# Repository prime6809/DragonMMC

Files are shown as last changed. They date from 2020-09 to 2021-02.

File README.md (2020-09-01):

# DragonMMC
This is the source repository for the DragonMMC project.

Currently it contains the following components :

6809 firmwars as exceuted by the CPU in the Dragon or CoCo.
AVR firmware as executed by the AVR microcontroller.
CPLD firmware as programmed into the XC95144XL CPLD chip on the board.

Various use and API documents are included in the Doc directory.

The primary developer uses the following environment to build the 
firmware : Programmer's notepad under windows, along with Cygwin.
The different firmwares are built using a Makefile.
Please see BUILD.txt in the Docs+explorer directory.

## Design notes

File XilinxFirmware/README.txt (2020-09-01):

Building Xilinx firmware

Open up project in Xilinx Webpack.

Select DragonMMC.v in the hierachy view.
Expand "Implement design" in the process view, and then double click on 
"generate programming file".
Once the programming file is complete double click on "configure target device".
Click OK to open impact (in a new window).

Within Impact :
Double click on "boundry scan" within "impact flows", this will open up a big 
blank pane with "Right click to add a device to the JTAG chain" in it.
Right click within this pane and from the popup menu select :
	Output file type->XSVF file->Create XSVF file.
	Enter an outout file name e.g. DragonMMC.xsvf
	You will then be prompted for the JED file, select the DragonMMC.jed
	
The JTAG pane will nwo display a graphic representing the xc95144xl, right click 
on this and select program and then 'OK' in the popup, the 'device' then be 
programmed with output going to the XSVF file.

Once this is done copy the DragonMMC.xsvf to your SD card as DGNMMC.SVF 
**NOTE** case and filename! Then program as usual.

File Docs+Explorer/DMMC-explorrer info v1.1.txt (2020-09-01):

DMMC explorer
=============

VARS
====
TRUE
FALSE
AEXEC true if AUTOEXEC is enabled
DS  true if DOS is enabled
CLOCK if clock is enabled at boot
DOT	 true if ._ files are hidden 
MAX  number of items in the folder
MR   max number of rows on screen
CF   current file DI position
CP   Current cursor print @ position
REFRESH Bolean set if the screen and DI needs refrshing
UPDATE boolean true if the screen should be updated
FILES number of files on screen
NEX number of known file extensions
NBYTES number of bytes in the inverse function

CC Boolean true if the system is CoCo

ROW the current row (starts at 1)4020
COL the current col (0 or 1)
page the current page (starts at 0)

DI$ (1..255) list of the items in the folder, blank is last entry
MD$ (1..4) mounted disks
FEXT$ (1-10) known file extentions
CC$ Cursor string
BC$ blank cursor
KEY$ Key input
WD$ The current worklng directory

Temp VARS
=========
CH
II
WI
C
I
FERROR%		filter error string
invalid$
N$
IN$
KEY 		assci vall of KEY$
EXT$		selected file extention (after pressing enter)
YL
OKtrustno1

COL
A$

Clock VARS
==========
YY YY$
MM MM$
DD DD$
HH HH$
MI MI$
DT$

-------------------------------------------

FILE EXTENTION DATA
1 .CAS 2800
2 .ROM 2400
3 .VDK 6200
4 .DGN 2600
5 .BIN 2600
6 .BAS 2600
7 .SSD 3400
8 .CCO 2600
9 .DSK 6200
10.SSC 3400
11.CCC 2400

------------------------------------------

10-200   Setup

200-350  Draw explorer screen
350 INKEY$ main

950 Exit point
1000 Populate folder array list
1200 read config vars: AEXEC, DOS, CLOCK
1400 SET config from vars: AEXEC, DOS, CLOCK

2000 RETURN key
2400 load ROM
2600 load DGN/BIN/BAS
2800 load .CAS file
2900 change folder

3000 UP KEY
3200 populate mounted disks array  MD$ 
3400 Load Snapshot

4000 DOWN key
4500 Page down
4600 Page up
4700 @ key go down tree

5000 RIGHT key
5200 New Folder
5500 Set snapshot directory

6000 list mounted disks
6200 mount a disks
6500 unmount disks
6700 mount .CAS file

7000 delete a file
7500 Set dir filter

8000 Version Info
8200 Change boot option
8500 clock adjust

9000 work out the current DI$() position - updates into CF

9200 Draw horz line
9400 Menu for unkown file types
9700 set clock

10000 HELP

20000 DATA for file extensions
20100 populate FEXT$ array
20200 Inverse DATA code
20400 Poke in the inverse function

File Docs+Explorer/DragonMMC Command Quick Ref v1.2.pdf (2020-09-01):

Date 22/09/2019 | V1.2

DragonMMC Quick Refernce Guide

Commands

CAT “pattern”
Lists the files in the current directory of the memory card that match the pattern. If no pattern is given, then all files are displayed.

CATP “pattern”
Lists the files in the current directory of the memory card that match the pattern. When no pattern is given, then all files are displayed. If the number of files exceeds what can be displayed on screen the results will be paged.

CWD “dirname”
Changes the current directory on the memory card to the specified directory.

CWDS “dirname”
Sets the directory where snapshots are saved. Dragon and CoCos have separate folders and must be set separately on each computer.

HELP / HELPX
Displays DMMC version information.

MCARTLOAD “filename”
MCARTLOADA “filename”
Loads the specified ROM file into the MMC card ram in the $C000-$FFEF area. Note: doing so will overwrite the MMC rom so MMC functions will no longer be available. MCARTLOADA allows the use of auto-starting cartridge images.

MCAS
Places the machine into cassette emulation mode, allows the use of emulator .CAS files with CLOAD, CSAVE etc.

MDELETE “filename”
Deletes the specified file from the current directory of the memory card, you will be prompted before deletion.

MDISK ON
Turns on disk emulation for the current platform and perform a cold reset.

MDISK OFF
Turns off disk emulation for the current platform and perform a cold reset.

MDISKC driveno,”filename”
Creates a blank disk image with the filename in drive driveno (1-4 for Dragon, 0-3 for CoCo). The disk image will require formatting before use (i.e. DSKINIT or DSKINI).

MDISKI driveno,”filename”
Mount disk image filename in drive driveno (1-4 for Dragon, 0-3 for CoCo).

MDISKL
List mounted disk images.

MDISKO driveno
Dismount disk image from driveno (1-4 for Dragon, 0-3 for CoCo).

MFILEC “file1”, “file2”
Copy file1 to file2.

MFILER“file1”, “file2”
Rename (or move) file1 to file2.

MMIRROR “filename”
MMIRRORA “filename”
Mirrors tape data as it’s loaded into the computer to a CAS format file. Type CLOAD or CLOADM to load a program, once loaded, press the snapshot button to finish the process.

MKDIR “dirname”
Creates the specified directory, on the memory card.

MLOAD “filename”
MLOAD “filename”, location
MLOADA “filename”
MLOADC “filename”
Load the previously saved BASIC or machine code program from the memory card. MLOADA will automatically RUN/Execute the program once loaded. MLOADC operates as MLOADA but first clears any active program and returns the machine to its power on state

MLOADS “filename”
Loads a previously saved snapshot from the memory card.

MMOUNTC
Closes the currently open cassette image file.

MMOUNTR “casfile”
Mounts a CAS file in read only mode.

MMOUNTW “casfile”
Creates and mounts a CAS file in write mode.

MSAVE “filename”
MSAVEM “filename”, start, end, entry
Save the BASIC or machine code program to the memory card. Note: the filename is used as specified and no extension is added.

MSETCFG flags
MSETCFG flags , <platform>
Set the configuration flags for the interface, value should be a bitwise or of the following values. Valid platform is:-
0 | System
1 | Dragon
2 | CoCo
If no platform is specified then the current platform (Dragon or CoCo) is assumed.

Valid flags for the System (DMMC) platform:-
Hex | Dec | Purpose
&H80 128 | Enable firmware updating from the memory card the next time
| | it is rebooted. **
&H04 4 | Enable auto .BAK creation when using MSAVE
&H02 2 | Disable the display of files beginning with ‘ ._’
| | (dot)(underscore) or ‘ _ ‘(underscore). This allows hiding of
| | Apple Mac meta data files.
&H01 1 | Enable debugging information to be sent to the AVR’s TTL
| | serial port.
** The firmware update flag is reset after a successful firmware update.

Valid flags for the Dragon and CoCo platforms:-
Hex | Dec Purpose
&H40 64 | Enable execution of the “AUTOEXEC” file, this should be a
| | BASIC program saved with MSAVE
&H20 32 | Enable DragonDOS (Dragon) or RSDOS (CoCo) emulation using
| | disk images. Also set by MDISK ON / MDISK OFF
&H10 16 | Enable the display of real time clock data and time at boot up.
&H08 8 | Enable the display of the firmware compile date at start-up.

MSETCFGCflags
MSETCFGC flags , <platform>
MSETCFGC will clear any bit that is set in the config byte, and leave alone any that is clear.

MSETCFGS flags
MSETCFGS flags , <platform>
MSETCFGS will set any bit that is set in the config byte, and leave alone any that is clear.

MSETDT “YYYY-MM-DD hh:mm:ss”
Set the real time clock date, used for date stamping files. Format MUST be:-
YYYY | Year 2000-2099
MM | Month 01-12
DD | Day of month 01-31
hh | Hour in 24 hour format 00-23
mm | Minutes 00-59
ss | Seconds 00-59
Note, that you must use a leading zero for values less than 10!

MTAPERUN “filename”
Turns on tape emulation, mounts the specified file as read only and loads the first file from the emulated tape. The first file loaded is automatically executed.

RETOKC
Re-tokenize the BASIC program in memory from Dragon to CoCo.

RETOKD
Re-tokenize the BASIC program in memory from CoCo to Dragon.

REWIND
Rewinds the cassette image file (.CAS) loaded into the virtual DMMC tape recorder.

Functions
Note: Functions ending in $ return a string, all others return an integer.

CFTYPE
Get the file type of the next file on an emulated cassette.
0 = BASIC, 1 = ASCII data/BASIC, 2 = Binary data or Machine Code, 255 = Invalid

CFTYPEE
Get the EXEC address of the next file on an emulated cassette.

CFTYPEL
Get the load address of the next file on an emulated cassette.

FINDFIRST$ “pattern”
Finds the file first based on the pattern, subsequent calls should be made to FINDNEXT$ Returns an empty string if no files are found.

FINDNEXT$
Finds the next file in the sequence started by FINDFIRST$ Returns an empty string when no more files are found.

MGETCFG
MGETCFG(<platform>)
Get the configuration flags, see MSETCFG for details, if no platform is supplied then the current platform (Dragon or CoCo) is assumed. See MSETCFG for details of the flags and platform. MGETCFG(255) can be used to find the current computer, 1=Dragon and 2=CoCo.

MGETDT$
Returns the current real time clock time, in the same format as MSETDT.

MGETINAME$ DriveID
Returns the filename of the disk image mounted on the specified drive id, returns an empty string if no disk is mounted on the specified drive.

SD$
Returns the directory snapshot files are saved into. See CWDS.

WD$
Returns the current directory name.

Other Useful Information

DMMC Explorer & Further Information
To simplify the use of the DMMC, a file ‘Explorer’ is available, which simplifies loading of programs and making config setting changes. The explorer, along with a full manual and firmware updates can be found at the following address:

http://www.archive.worldofdragon.org/index.php?title=DragonMMC_SDCard

The designer of DragonMMC can be also contacted by email at:

dragonmmc AT ramoth DOT org DOT uk

(replace AT with @ and DOT with . remove all spaces!)

AUTOEXEC
The DMMC allows automatic execution of a program on a cold boot. The AUTOEXEC file should be a BASIC program in the root directory of the memory card saved with MSAVE. To run the AUTOEXEC program at boot time, ensure the option is enabled with MSETCFG. There are separate AUTOEXEC files for Dragon and CoCo, this allows the same card to be used in both computers. Dragon has an AUTOEXEC file extension of .DGN and CoCo .CCO.
To bypass the running of the AUTOEXEC, press the space bar during the cold boot.

SETTINGS
The DMMC saves the currently mounted virtual disks and the snapshot folder to the binary SETTINGS file in the root directory of the memory card. There are separate SETTINGS files for Dragon and CoCo, this allows the same card to be used in both computers. Dragon has a SETTINGS file extension of .DGN and CoCo .CCO.

Long File Names
Whilst the Dragon (and CoCo) is limited to short filenames (8.3 format) on the memory card, long filenames on the card will be shortened to fit the short filename scheme.
Starship Chameleon.CAS | Modern long filename
Starsh~1.CAS | Displayed as short filename on a modern computer
STARSH↑1.CAS | As displayed by the CAT command
STARSH↑1.CAS | As entered from the Dragon keyboard

How this is used on the Dragon:-
CAT
STARSH↑1.CAS
MTAPERUN “STARSH↑1.CAS”

Filenames containing the “ ^ ” (caret symbol) are not supported.

File Extensions
Recommended file extensions to distinguish different files types:-
Extension File Type
BAS | BASIC programs saved direct to memory card (MSAVE).
BIN | Machine Code programs/data saved direct to memory card (MSAVE).
CAS CCO | Cassette (emulator) images.
| BASIC or Machine Code programs saved direct to the card (MSAVE).
CCC | CoCo cartridge (ROM) Image.
DGN | BASIC or Machine Code programs saved direct to the card (MSAVE).
DSK | CoCo Floppy Disk Image. DSK is recommended for CoCo format disks.
ROM | Dragon cartridge (ROM) Image.
VDK | Dragon Floppy Disk Image. VDK is recommended for Dragon format disks.

DMMC Snapshot Button
Pressing the Snapshot button on the DMMC will pause the execution of the current program and show the snapshot menu.
Key | Function
W | Warm reset, the equivalent of pressing the reset button.
C | Cold reset, equivalent to when the power is turned on.
S | Saves the current state of the computer to the filename specified, to the folder specified in SD$ by CWDS.
L | Loads a snapshot from the folder specified in SD$ and returns the computer to the same state that it was saved.
U | For future expansion.
X | Exits the snapshot menu, has the effect of un-pausing the computer.

Force Cold Reset Button
When running ROM (cartridge) images, pressing the Force Cold Reset Button whilst pressing the computers reset button will perform a cold reboot without using the power switch.

FLEX & OS9 Operating Systems
To allow booting of the FLEX operating system please download the latest FLEX unities.

At the time of writing DMMC does not support OS9.

Notes
This quick reference covers Dragon MMC F/W V1.2 onwards.

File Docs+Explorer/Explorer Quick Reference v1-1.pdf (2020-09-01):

# Dragon MMC Explorer Quick Reference

Current

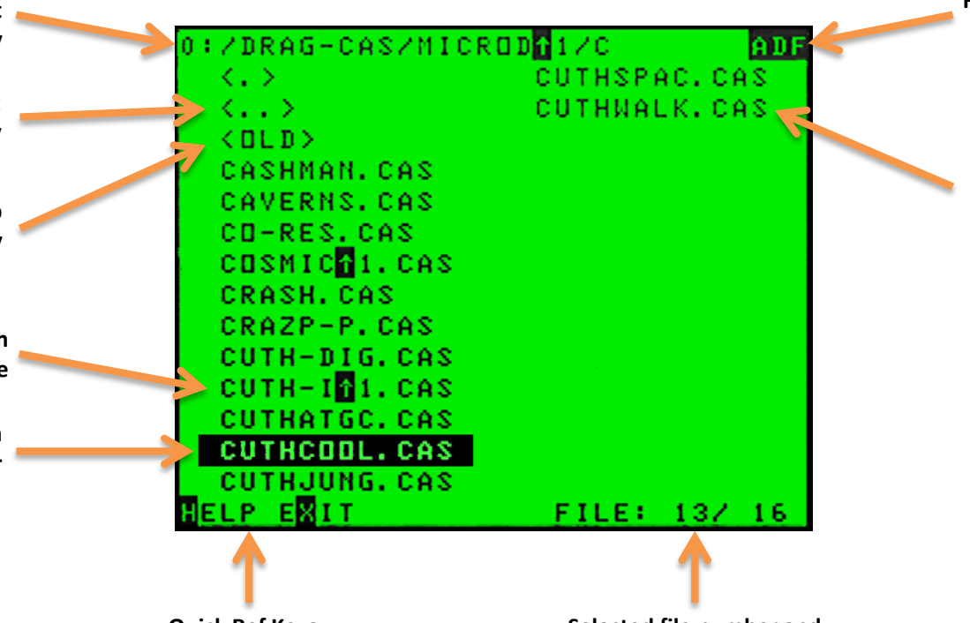
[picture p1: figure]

Directory

Parent
Directory

Sub
Directory

Selection
Cursor

CAS file with
long filename

Flags:
A = Autoexec on
D = DOS Enabled
F = File Filter set

Selected file number and
number files in the directory
(max 255)

Quick Ref Keys:
Press H for Help and
X to exit

Quick Ref V1.1 05/2018

Cassette image
(CAS) file

Navigation:
↑ = Move Up
↓ = Move Down
→ = Right Column (End)
← = Left Column
@ = Parent Directory
/ = Root Directory

Q = Page Up
A = Page Down
R = Refresh List
X = Exit
ENTER = Select

Functions:
D = Delete File
F = Set File Filter
L = List Mounted Disks
M = Mount .CAS
N = New Directory
U = Unmount Disk

Misc:
B = Boot Settings
C = Set Clock
H = Help
S = Set Snapshot Dir
V = Version Info

INSTALLING THE DMMC EXPLORER ============================

1. Go here:
http://www.archive.worldofdragon.org/index.php?title=DragonMMC_SDCard and download the explorer.
2. Copy the explorer into the home/root directory of the memory card. N.B: File extension .DGN is for the Dragon and .CCO for the CoCo.
3. To enable the explorer to auto run at boot time, rename the explorer to AUTOEXEC, e.g.:
AUTOEXEC.DGN or AUTOEXEC.CCO
4. With the computer off, place the memory card into the DMMC.
5. Turn on the computer.
6. If the explorer starts automatically all is well, you’re done and there is no need to continue.
7. On a Dragon start the explorer manually with:
MLOADA "AUTOEXEC.DGN"
8. On a Coco start the explorer manually with: MLOADA "AUTOEXEC.CCO"
9. Press 'B' to go into the boot menu.
10. Press 'A' to enable AUTOEXEC.
11. Press 'X' to save the settings.
12. Reboot your computer.
13. The explorer should now start automatically, just copy your CAS and ROM files on the SD card and Njoy!

R.Harding

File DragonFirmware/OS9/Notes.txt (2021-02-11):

Notes on getting OS-9 working on DragonMMC.

Requirements :

mboot and mdisk + d0,d1,d2,d3 modules on the modules.os9 
disk image
LOADAT and MODBUST OS-9 commands on the mmcutil.os9 disk image.
LWTOOLS (specifically lwasm) available from http://www.lwtools.ca/
The Toolshed tools from the Nitros9 project.

The disk image was built with MESS running DragonData OS-9.

Procedure :

Run make in this directory, this will build all the required modules and
make two disk images modules.os9 and mmcutil.os9

Create files containg the mmc bootlist (blmmc) :
This is created on the modules disk but is included here for refference.
This is also the list for the Dragon, the CoCo list will be slightly different
****************** NOTE ***************** 
** MUST have correct (CR) line endings **
*****************************************
OS9/IOMAN
OS9/RBF
MMC/DDISK
MMC/D0
MMC/D1
MMC/D2
MMC/D3
OS9/SCF
OS9/KBVDIO
OS9/TERM
OS9/T1
OS9/P1
OS9/PRINTER
OS9/P
OS9/PIPEMAN
OS9/PIPER
OS9/PIPE
OS9/CLOCK
OS9/SYSGO
OS9/SHELL

Boot OS-9 with the following disks in drives :
d0: Standard OS-9 boot disk
d1: modules.os9 
d2: mmcutil.os9
d3: Target disk to become mmc boot, e.g. a copy of standard boot disk.

Put the disk to be prepared for mmc boot in /d3 a good example would 
be a copy of the Dragon OS-9 disk, but ensure that it has enough room
for the bootfile.

In the OS-9 shell change directory to /d1/os9 and run modbuster, then 
change back to the root of d1

chd /d1/os9
/d2/cmds/modbust /d0/OS9Boot
chd /d1

Alternately, modbust can have the output path specified :

/d2/cmds/modbust /d0/OS9Boot /d1/os9

This will extract the modules from the current OS-9 boot file to the
/d1/os9 folder

Before making the MMC boot disk we need to replace the boot module in 
memory with the MMC one, this is safe to do as this code is only used 
whilst booting the system. Once the main disk driver is running it is
safe to replace it.

To do this we will need to use the LOADAT command to load the new boot
module over the top of the old one. The new one must obviously be smaller
or equal size. 

To find the Load address use the MDIR command with the E flag note the 
starting address of boot (e.g. for me it was $FD75), you will also need
the length of the replacement boot file this can be found with 
DIR E /d1/mmc

Once you have these you can load the new boot file :

/d2/cmds/loadat FD75 13A /d1/mmc/boot

We are now ready to to make the boot disk with :

os9gen /d3 < blmmc

This will make the boot file on that disk, rewrite to boot track and
link the new boot file, this should now be able to be booted from the 
DragonMMC.

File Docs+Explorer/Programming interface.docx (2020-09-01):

DragonMMC programming interface.

For Firmware V1.30 2020-05-10.

DragonMMC consists of a ROM containing 6809 code which communicates with an AVR microcontroller which handles all of the SD card and clock related operations. The AVR microcontroller has firmware that talks directly via SPI to the SD card, and handles the FAT filesystem on that card removing the need for the 6809 to do this directly.

The 6809 code communicates with the AVR code through a series of I/O ports that are handled by the onboard Xilinx XC95144XL CPLD, the details of these will be outlined below.

Commands are issued by writing their byte code to D_CMD_REG status is read back from the same register once the AVR stops being busy (AVR busy bit of D_STATUS_REG is clear).

Generally interchange between the 6809 and AVR will use one of three protocols, bulk data transfer in, bulk data transfer out and latched byte out.

With a transfer in command the 6809 will first issue a CMD_INIT_WRITE command, send over the data a byte at a time to the D_WRITE_DATA_REG and then issue a command to be carried out on that data e.g. write it to a file, update the clock etc.

Transfer out commands the 6809 will issue the command, get a status byte and if successful, will then issue a CMD_INIT_READ command and then retrieve the data one byte at a time from D_READ_DATA_REG e.g. read data from a file.

Latched byte commands have parameters that are single bytes (up to a maximum of 16), which should be written one after another to D_LATCH_REG, and then the command issued in the standard way. NOTE The latch write pointer is reset to the first byte after a write to the D_CMD_REG a good way of ensuring the byte buffer is flushed is to execute a CMD_NOP.

NOTE All transfers to / from the AVR should check the busy and handshake flags to ensure correct data transfer between the two.

NOTE for all transfers IN and OUT are relative to the AVR, e.g. Data or Latch In is 6809→AVR, Data Out is AVR→6809.

Hardware Details.

The ports that the 6809 firmware uses to communicate are all in the $FF50-$FF5F region, and are detailed below :

$FF50 D_CMD_REG Command / Result

All commands are written to this port, and status is read back.

$FF51 D_LATCH_REG Latch

Used by some commands as a single byte parameters, where a bulk data transfer is not needed the latch register has a 16 byte buffer behind it, each byte written to the latch register is put in the next available buffer position. NOTE the buffer position is RESET to 0 after a write to the command register EXCEPT for the CMD_INIT_WRITE command. This is done so that latch and data bytes may be passed in any order. A good way to ensure the byte buffer is clear is to send a CMD_NOP.

$FF52 D_READ_DATA_REG Read data

When transferring data from the AVR to the 6809, it is read a byte at a time from this register.

$FF53 D_WRITE_DATA_REG Write data

When transferring data from the 6809 to the AVR, it is written a byte at a time to this register.

$FF54 D_STATUS_REG AVR status

This register contains the status of the AVR, that the 6809 can read, including the various handshake bits.

Bit Purpose

0 AVR_Busy when this bit is set it indicates that the AVR is busy processing a command, further commands / data should not be sent until this bit is clear.

1 DragonW_AVRR handshake line from 6809→AVR this bit is set when the 6809 writes a command / data to the registers above, it is cleard once the AVR has read the sent data, indicating that it is ready to receive more data (if busy is not set).

2 AVRW_DragonR handshake bit from AVR→6809 this bit is set when the AVR has written data and it is ready to be read by the 6809. This bit is cleard when the 6809 reads the data.

3 unused

4 unused

5 unused

6 unused

7 unused

$FF55 D_PIA_MAP PIA redirect (write only)

Writing to this register enables the re-directing of PIA reads at $FF20 to come from the CPLD instead, this allows the AVR to emulate the FSK input from a tape. Bit 0 is used to control this, setting it to 1 enables emulation, setting it to 0 disables it.

$FF56 D_RAM_CTRL RAM / ROM control register

Controls the paging of the onboard 6809 firmware ROMS and of the onboard mirror RAMS.

Bit Purpose

0 Enable RAM in $8000-$FEFF, this disables the internal ROMs in this area.

1 Write protect the RAM between $8000-$FEFF.

2 Enable the routing of the Q line to the CART pin, to allow a loaded cartridge image to auto start.

3 Enable writes to the $8000-$FEFF to go to the Flash ROM instead of the RAM.

4 A14 of the Flash ROM, this is used to control which bank of 16K is paged into the $C000- $FEFF area. As supplied the Dragon code paged in when this bit is 0, and the CoCo code is

paged in when this bit is 1. On reset the firmware checks which machine it is running on and

sets this as needed.

5 When set the interrupt vectors at $FFF0-$FFFF are read from the top of the first bank of 32K of the SRAM. When cleared they are read from the ROM as normal.

6 Enable snapshot button to generate an NMI to the 6809.

7 Write protect for the interrupt area of RAM.

$FF57 unused.

Not currently used.

$FF58 D_SAMBITS_MSB

$FF59 D_SAMBITS_LSB SAM bits

Because the SAM does not have a connection to the 6809 data bus, it’s programmed state can not normally be determined. The CPLD on the board, mirrors writes to the SAM registers so the they may be read back, via these two locations. $FF58 contains the 8 most significant bits and $FF59 contains the least significant bits. This allows the SAM’s state to be saved and restored e.g. when creating a snapshot.

$FF5A / $FF5B RAM bank read / write registers

If enabled in the RAM / ROM control register (and in map mode 0) the top 32K of the 6809 memory map can be replaced by RAM. This is generally used by the CAS file loader to copy the basic and MMC roms to RAM and then patch them to redirect tape operations to read from a .CAS file on the SD card. The RAM socket may take a static RAM chip up to 512K, the bottom 4 bits of these registers control which block of 32K within the SRAM is accessed. Note that even with the RAMS paged out (in the RAM/ROM control register), writes to this area will STILL go to the selected RAM bank. The exception to this is if the Flash write bit is set in the RAM / ROM control register to allow updating of the firmware.

$FF5C to $FF5F

Currently unused.

Command Specification.

The following is a numerically ordered list of the commands that may be sent from the 6809 to the AVR. Along with their symbolic names as defined in the 6809 and AVR firmware definition files. Wherever possible these should be used directly by including them in any project that is directly talking to the firmware.

Note some of these commands will first require data to be sent to the AVR for them to operate on, with the CMD_INIT_WRITE, followed by sending the data to the data out register. This will be noted in the following specifications, by marking the command with Data In.

Commands tagged with Data Out, if successful will place data in the AVR’s buffer to be read by the 6809 by issuing a CMD_INIT_READ and then reading the data from the read data register.

All commands will return a status byte which can be checked for errors, except where noted.

Directory commands

CMD_DIR_OPEN $00 Data In

Open the specified directory / wildcard and prepare it to be read this can be used to read the entire contents of a directory by specifying no wildcard (*.* will be assumed) or to select a group of files e.g. *.cas

CMD_DIR_READ $01 Data out

Reads the next directory entry from a previously opened (with CMD_DIR_OPEN) directory, if no more entries are available the STATUS_LAST bit will be set.

The entry is returned :

offset size use

0 n filename, if directory will be surrounded by < and >

n+1 1 zero terminator

n+2 1 file attributes

n+3 4 file size

CMD_DIR_CWD $02 Data In

Change to the specified directory.

CMD_DIR_GETCWD $03 Data Out

Return the currently selected directory.

CMD_DIR_MAKE $04 Data In

Create the specified directory.

CMD_DIR_REMOVE $05 Data In

Remove the specified directory.

CMD_DIR_SET_SNAPPATH $06 Data In

Set the path to be used when creating snapshots via the NMI menu.

CMD_DIR_GET_SNAPPATH $07 Data Out

Get the current snapshot path.

File Commands

File commands generally operate on a file identified by a file ID. The file id will be from 0 to NO_FILES (as defined in the AVR firmware, currently set to 6). The file ID will generally be the first thing written to the latch register.

CMD_FILE_CLOSE $10 Latch in

Close the current file, latch contains the file id to close.

CMD_FILE_OPEN_READ $11 Latch In, Data In

Open the specified file who’s name is in the AVR buffer, and who’s ID is latched for reading

CMD_FILE_OPEN_IMG $12 Data In

Open the specified disk image, the disk image number is specified as the first byte of data immediately followed by it’s zero terminated filename.

CMD_FILE_OPEN_WRITE $13 Latch In, Data In

Open the specified file who’s name is in the AVR buffer for writing.

CMD_FILE_DELETE $14 Data In

Delete the specified file who’s name is in the AVR buffer .

CMD_FILE_GETINFO $15 Latch In, Data In

Get information about the specified ID returned is as as follows :

Offset Size Purpose

0 4 File size

4 4 File starting block number (within SD card)

8 4 Current file pointer

12 1 File attributes

CMD_FILE_OPENAUTOD $16

Open the Auto start file for the Dragon (AUTOEXEC.DGN)

CMD_FILE_OPENAUTOC $17

Open the Auto start file for the CoCo (AUTOEXEC.CCO)

CMD_FILE_OPEN_OVERWRITE $18 Latch In, Data In

Open the specified file for overwrite, removing any previous file contents.

CMD_FILE_OPEN_SNAPR $19 Latch In, Data In

Open the specified file from the configured snapshot directory for reading.

CMD_FILE_OPEN_SNAPW $1A Latch In, Data In

Open the specified file from the configured snapshot directory for writing.

CMD_FILE_OPEN_STREAMR $1B Data In

Open a file for stream reading, currently does nothing, as is just a placeholder for completeness.

CMD_FILE_OPEN_STREAMW $1C Data In

Open the specified file for streaming to this is used by MMIRROR to rapidly copy bytes from the incoming (real) cassette to the SD card. Puts the AVR in an interrupt driven mode where all bytes written to the data port are double buffered and written to the card, whilst in this mode the AVR will ignore any further commands until the snapshot button is pressed to terminate streaming, close the stream file and return to normal mode.

Will always use file id 0.

CMD_FILE_COPY $1D Data In

Copy a file to a new file both on the SD card. The filenames are placed in the buffer with the zero terminated source at offset 0, and the zero terminated destination, immediately after the zero terminator of the source.

CMD_FILE_RENAME $1E Data In

Rename a file on the SD card, data buffer should be formatted as for CMD_FILE_COPY.

CMD_FILE_OPENCRE_IMG $1F Data In

Open a disk image file if it exists, if it does not exist create it first. Buffer should be formatted as for CMD_FILE_OPEN_IMG.

Data Transfer and File operation Commands.

CMD_INIT_READ $20

Move the AVR’s data pointer to the beginning of the buffer and prepare it to send data to the 6809.

CMD_INIT_WRITE $21

Move the AVR’s data pointer to the beginning of the buffer and prepare it to receive data from the 6809.

CMD_READ_BYTES $22 Latch In, Data Out

Read specified number of bytes from open file. The number of bytes to read must have been previously written to the latch register.

CMD_WRITE_BYTES $23 Latch In, Data In

Write specified number of bytes from open file. The number of bytes to write must have been previously written to the latch register. The bytes to write must have been previously loaded into the AVR’s buffer with CMD_INIT_WRITE, and then written to the buffer by sending to the Write data register.

CMD_REWIND $24

Return the file pointer to the beginning of the file.

CMD_SEEK $25 Data In

Seek a file to a specified position….not yet implemented.

CMD_TELL $26 Data Out

Report the current filepointer position of a file, not yet implemented.

Utility commands.

CMD_GET_STRLEN $30

Get the length of the zero terminated string in the AVR buffer. Note does NOT set status.

CMD_EXEC_PACKET $3F Data In

Read and write EEPROM…..not used, may be removed.

DOS Emulation / Virtual floppy commands

CMD_LOAD_LBA $40 Data In

Load the logical block address of the required sector, buffer should be preloaded with :

Offset Size Purpose

0 1 Drive number 0..3

1 4 Logical sector number (little endian e.g. lsb first)

CMD_GET_IMG_STATUS $41 Latch In

Returns the file attributes of the specified image number, drive number should be written to the latch register, attributes returned immediately. Note does NOT return a status.

CMD_GET_IMG_NAME $42 Data In

Returns the path names of the specified images, the drive IDs of the first and last drive images to retrieve should be written to the first two bytes of the buffer. On successful completion the buffer will contain as many zero terminated strings as drives requested. If a drive currently has no image mounted then a zero length string will be returned in it’s position.

CMD_READ_IMG_SEC $43 Data Out

Read the specified sector from the image, the sector will have been previously specified with either CMD_LOAD_LBA or CMD_IMG_SEEK and CMD_LOAD_HR. On successful completion the sector data will be in the AVR’s buffer and can be read in the normal manner.

CMD_WRITE_IMG_SEC $44 Data In

Write the specified sector to the disk image, the disk will have had the write position set with either CMD_LOAD_LBA or CMD_IMG_SEEK and CMD_LOAD_HR. The sector data should then be loaded into the AVR’s buffer before issuing this command.

CMD_SER_IMG_INFO $45

Serialize drive info, saves mounted drives to the settings file in the rood directory of the SD card.

CMD_VALID_IMG_NAMES $46

Check to see if image names are valid.

CMD_IMG_UNMOUNT $47 Data In

Close the specified drive ID’s image file flushing any data and invalidate the drive. The drive id should be loaded into the AVR buffer before issuing this command.

CMD_IMG_SEEK $48 Data In

Seek the virtual disk to the specified disk track, the AVR buffer should be loaded with the drive ID, followed by the track to seek to.

CMD_CREATE_IMG $49 Data In

Create a new disk image with the specified geometry. The AVR buffer should be filled as follows :

Offset Size Purpose

0 1 Drive ID 0..3

1 2 Track count LSB first

3 1 Head count

4 1 Sectors per track

The disk image file should have been previously associated with the drive by using CMD_FILE_OPEN_IMG

CMD_GET_FDC_STATUS $4A

Get the emulated disk system’s status. The status byte is an emulated version of the status byte that would be returned by the WD2797 / WD1793 floppy controller. The status byte is written immediately, a normal status is NOT written first.

CMD_READ_NEXT_IMG_SEC $4B Data Out

Increment the LBA offset by 1 and read the next sector into the AVR buffer, currently broken DO NOT USE

CMD_LOAD_HR $4C Data In

Load the specified head and sector (record) number into the virtual disk, the AVR buffer should be setup as follows :

Offset Size Purpose

0 1 Drive ID 0..3

1 1 Head number

2 1 Sector number

Cassette emulation commands.

CMD_CAS_FTYPE $50 Data Out

Attempt to determine the type of the next file on the emulated cassette and return it. On completion the buffer will contain the single byte filetype.

CMD_CAS_EMULATE2 $5E

CMD_CAS_EMULATE $5F

Emulate the tape by way of sending FSK bits to the PIA, these are to allow reading of the SD card to flash the flash ROM image with no firmware already present. They should be used as follows, from basic :

POKE &HFF55,1 : REM Turn on PIA replacement

POKE &HFF50,&H5F : REM give command to AVR

CLOADM

EXEC

These commands should not need to be used under normal circumstances.

More utility commands

CMD_GET_CARD_TYPE $80

Get the type of card MMC / SD / SDHC etc. Type is returned immediately, command does NOT return a normal status.

CMD_SET_BUSY $90

Set the AVR into busy mode. Should only be used for testing.

CMD_NOP $91

No operation, does nothing but clear the current busy status.

CMD_SYNC $92

Synchronizes any pending data to the card.

Old AtoMMC commands.

The following are recognized by the DragonMMC AVR firmware but may be removed in future, they where provided for backward compatibility with the AtoMMC from which the AVR’s firmware was derived.

CMD_GET_PORT_DDR $A0

CMD_SET_PORT_DDR $A1

CMD_READ_PORT $A2

CMD_WRITE_PORT $A3

Date and Time related commands.

CMD_GET_DATETIME $C0 Data Out

Fetch the current data and time from the real time clock, the buffer is filled as follows :

Offset Size Purpose

0 4 Year in ASCII e.g. 2020

5 1 - seperator

6 2 Month in ASCII, left zero padded.

8 1 - seperator

9 2 Day of month ASCII, left zero padded.

11 1 Space seperator

12 2 Hours in ASCII, 24 hour format, left zero padded

14 1 : seperator

15 2 Minutes in ASCII, left zero padded

17 1 : seperator

18 2 Seconds in ASCII, left zero padded.

20 1 Zero terminator

This is basically the time and date in ASCII in the format YYYY-MM-DD hh:mm:ss

CMD_SET_DATETIME $C1 Data In

Set the real time clock date and time, the buffer should first be filled in in the same format as returned by CMD_GET_DATE.

Firmware information commands

CMD_GET_FW_VER $E0 Data Out

Get the firmware version along with it’s compile time in ASCII, the buffer will return :

Offset Size Purpose

0 1 Bootloader version packed into a byte with bits 7..4 being the Major version and bits 3..0 being the minor version.

1 n n bytes of zero terminated string containing the firmware build date.

CMD_GET_BL_VER $E1 Data Out

Get the AVR bootloader version data, output buffer formatted as for CMD_GET_FW_VER above.

Configuration byte commands

CMD_GET_CFG_BYTE $F0

Get the specified platform’s configuration byte, the required platform ID must first be written to the Latch register.

The valid platforms are :

PLAT_SYSTEM $00 DragonMMC system

PLAT_DRAGON $01 Dragon

PLAT_COCO $02 CoCo

The configuration byte is returned immediately a normal status is NOT returned.

CMD_SET_CFG_BYTE $F1 Latch In

The Platform ID and config byte are written to the Latch register and then this command should be executed The bytes should be written in the following order :

Platform id, config byte.

CMD_SET_PLATFORM $F2 Latch In

Tell the AVR what platform the 6809 end is running on either PLAT_DRAGON or PLAT_COCO

CMD_READ_AUX $FD

Return the latched address of the last register written. Unused, may be removed in future.

CMD_GET_HEARTBEAT $FE

Each time it is called the heartbeat byte is returned, this will be a sequence of $55 and $AA bytes alternating on each call.

Status codes.

For most DragonMMC firmware commands STATUS_COMPLETE set when a command completes.

If an error condition occours, then STATUS_ERROR should be set, this way we can use the 6809 BITA / BITB instructions to test for error, this also allows us to BMI on error.

Multi-phase commands like getting directory entries return status complete after each entry. On the last entry this is or'd with STATUS_LAST.

Status / error name Returned code

STATUS_ERROR $80

STATUS_COMPLETE $40

ERROR_MASK $7F

To be or'd with STATUS_COMPLETE

STATUS_LAST $01

To be or'd with STATUS_ERROR since STATUS_ERROR can also return a fatFS error code we must make sure these are in a non overlapping range.

ERROR_INVALID_CMD $20

ERROR_INVALID_IMAGE $21

ERROR_NO_DATA $22

ERROR_INVALID_DRIVE $23

ERROR_READ_ONLY $24

ERROR_ALREADY_MOUNT $25

ERROR_INVALID_TIME $26

ERROR_INVALID_FID $27

Configuration byte bitmasks.

System platform (0)

CFG_ENABLE_BOOTLOAD $80

Enable bootloader to check for updated AVR firmware on next AVR restart, if found updated firmware will be flashed.

CFG_DEBUG_LOG_REPLY $08

Unknown, unused!

CFG_BACKUP_FILE $04

Should we maintain .BAK files when opening files for overwrite that already exist.

CFG_HIDE_MAC $02

Should we hide the special files that Apple Mackintosh’s finder creates.

CFG_DEBUG_LOG $01

Enable verbose AVR firmware debug messages to it’s TTL serial port, this should normally be off, but may be turned on if developing the firmware, not turning this on will noticeably slow down some operations.

Dragon (1) or CoCo (2) platforms.

CFG_ENABLE_AUTOBOOT $40

Should the autostart file be searched for at power on or reset time. This will be AUTOEXEC.DGN for the Dragon or AUTOEXEC.CCO for the CoCo. These files should be a standard basic program saved with MSAVE.

CFG_ENABLE_DOS $20

Should DOS emulation be enabled or disabled.

CFG_SHOW_DATETIME $10

Should the RTC data and time be shown at startup.

CFG_SHOW_COMPILE $08

Should the firmware compile time be shown at startup.

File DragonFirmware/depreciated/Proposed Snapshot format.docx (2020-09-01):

Proposed snapshot format

1 Word : value of system stack pointer

1 Word : SAM bits (so memory config can be determined).

32K / 64K : memory dump of RAM.

May also need a signature word.

Snapshot method :

Enter via NMI (or simulated NMI)

Get and stack word containing SAM bits.

For Each PIA, get the registers in the following order : CRA,DDRA, PA, CRB, DDRB, PB and stack them.

Create snapshot file.

Write value of S and copy of SAMBITS.

Write a dump of RAM 32K / 64K.

RTI

Restore method :

Open snapshot file & validate. (AVR task?).

Retrieve system stack pointer & SAM bits (to determine memory config).

Set S to be retrieved pointer.

Restore memory being careful about not tramping on working storage

Pull PIA registers from stack, need to restore DDR before port reg so something like

Restore CRA, set ddr bit, restore DDRA, reset ddr bit, restore PA, restore CRA.

We restore CRA twice then we will always set the DDR bit to the same as it was when the snap was created.

Restore SAM bits.

Return (to restored program RTI).

Initially do this via a command that simulates the interrupt, then write a UI that is triggered by snap button on interface.

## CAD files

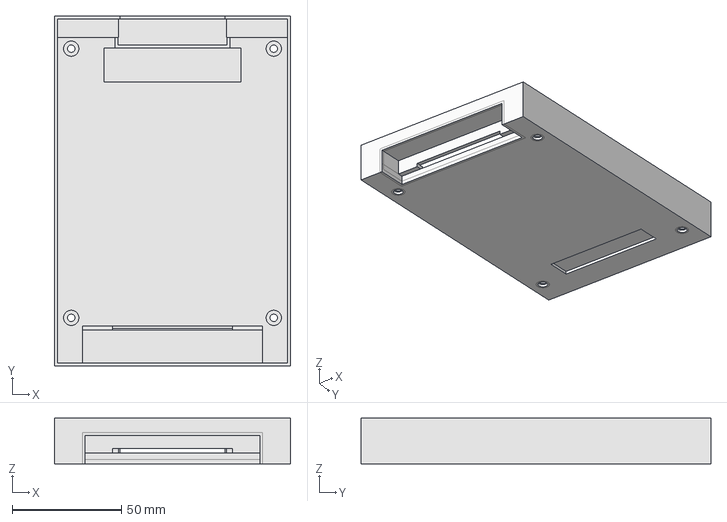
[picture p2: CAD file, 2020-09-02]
Case/DragonMMCBottom-v3.FCStd
108.0 x 160.0 x 21.0 mm

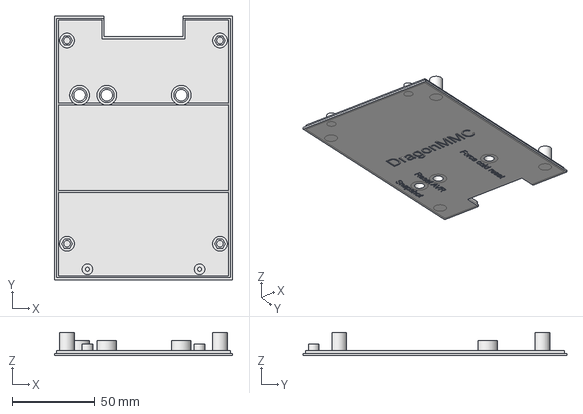
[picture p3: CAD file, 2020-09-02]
Case/DragonMMCTop-v5.FCStd
108.0 x 160.0 x 14.2 mm

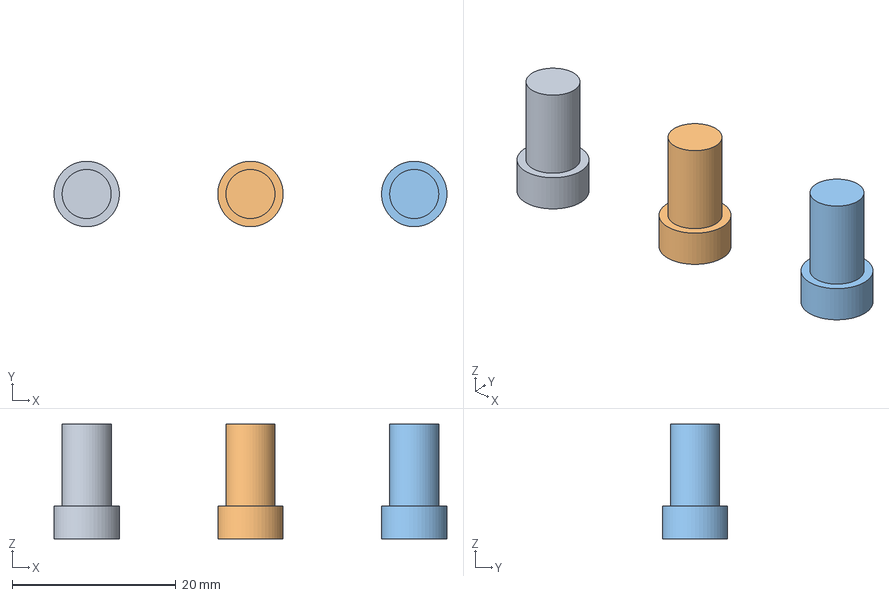
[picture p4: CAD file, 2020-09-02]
Case/DragonMMCButtons-v3.FCStd
48.0 x 8.00 x 14.0 mm
Button 1
Button 2
Button 3

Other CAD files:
Case/DragonMMCBottom-v3.stl
Case/DragonMMCButtons-v3.stl
Case/DragonMMCTop-v5.stl

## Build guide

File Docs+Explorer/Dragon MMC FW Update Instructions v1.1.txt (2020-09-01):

Dragon MMC F/W Update Instructions
==================================

Getting Started
---------------
The firmware files for any update should be placed onto a freshly formatted memory card. Some releases require updates to multiple components, ensure all updates in each release are applied for consistent operation.

N.B. As with all firmware updates do NOT reset or turn off the computer whilst an update is in progress. 

Update AVR Firmware
-------------------
Files required on memory card: DGNMMC.BIN

1) Turn on the computer with the memory card in the slot
2) At the BASIC prompt type:
     HELP
3) For Dragon MMC V1.0 type:
     MSETCFG &H80,0
4) For Dragon MMC V1.1 or greater type:
     MSETCFGS &H80,0
5) Press the reset AVR reset button 
6) The DMMC LEDs will flicker for about 5 seconds whilst the upgrade takes place
7) Allow at least 20 seconds for the operation to complete
8) Turn the computer off and on for the change to take effect

Update 6809 ROM
---------------
Files required on memory card: DGNMMC.ROM, FLASH.DGN

1) Turn on the computer with the memory card in the slot 
2) At the BASIC prompt type: 
     MDISK OFF
3) After the reboot, turn the computer off
4) Ensure the ROM Write Protect jumper (JP2) is set to WE 
5) Turn on the computer with the memory card in the slot 
6) At the BASIC prompt type:
     MLOADA"FLASH.DGN"
7) The update progress is displayed on screen
8) When prompted press a key to reset the computer
9) If using disk emulation at the BASIC prompt type: 
     MDISK ON
10) After the reboot, turn the computer off and move the jumper back to RO
11) Switch the computer back on

Update the CPLD
---------------
Files required on memory card: DGNMMC.SVF

1) Turn the computer off 
2) Ensure the update CPLD jumper 1 to set to ON
3) Turn the computer on with the memory card in the slot
4) The CPLD will be automatically updated, this may take 30 seconds to a minute, when complete both DMMC LEDs will go out
Note: the ROM and RAM are enabled by the CPLD, so whilst this is taking place the computer will display just the normal BASIC (C) message.
5) When complete switch the computer off and remove the update jumper
6) Switch the computer back on

Update Instructions Ver 1.1
Dragon / CoCo SD/MMC Mk 2.40
Date 05/05/2018

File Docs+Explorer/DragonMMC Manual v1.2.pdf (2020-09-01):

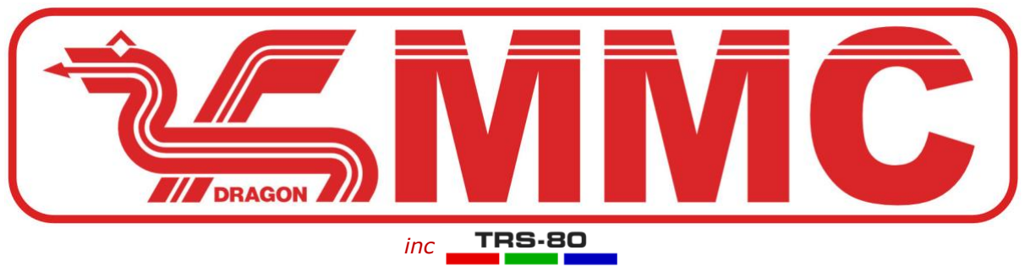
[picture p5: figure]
inc

# AN INTRODUCTION TO DRAGON MMC

by

## Phill Harvey-Smith

and

## Richard Harding

## A Manual for the Dragon MMC SD Card Interface

Version V1.2 09/2019
Covers Dragon MMC F/W 1.20+

Acknowledgements

I would like to thank all the people who have helped along the way to making the DragonMMC a reality, these include:

Charlie Robson, who allowed me access to the source for his AtoMMC interface for the Acorn Atom, on which the AVR microcontroller code for the DragonMMC interface is based.

Simon Hardy & the other members of Retro Computer Museum Leicester for doing some initial testing when I first started the project. Simon also did a sterling job demonstrating the later board at the 2017 Dragon meeting.

Bas Gialopsos and Richard Harding for exhaustive testing and feedback. This has led to the eradication of a whole load of major bugs in the interface firmware. Not to mention the implementation of several facilities that had not occurred to me.

Richard Harding, for writing the documentation and taking a major task off my hands.

Chris Poacher for the DMMC logo concept.

Finally, an obligatory shout out for my wife Lesley, for putting up with me talking about retro computers to her for all these years

Phill Harvey-Smith
2017

CONTENTS

GETTING THE SHOW ON THE ROAD | 7
LOADING UP | 12
SNAPPY DRAGON MMC | 18
GOING NATIVE | 20
TROUBLESHOOTING | 23
DRAGON MMC COMMANDS | 26
DRAGON MMC FUNCTIONS | 52
DRAGON MMC MISCELLANEOUS | 59

### INTRODUCTION

WELCOME

DMMC for the Dragon and CoCo in the modern age

When the Dragon and CoCo were in production, it was science fiction that every piece software ever released for them could be stored on a ‘solid state’ drive with no moving parts.

!!! Science fiction has now become science fact !!!

The Dragon MMC allows a massive software catalogue to be available at your fingertips that can be loaded in a matter of seconds.

Don’t’ forget to keep up to date with new firmware etc. at the following address:

http://www.archive.worldofdragon.org/index.php?title=DragonMMC_SDCard

To simplify the use of the DMMC an ‘Explorer’ can also be found at the address above.

DMMC Hardware Overview

The Dragon MMC is compatible with the following computers:-
a) Dragon 32
b) Dragon 64*
c) Draco 64*
d) Radio Shack (Tandy) CoCo 1**
e) Radio Shack (Tandy) CoCo 2**

*As the DMMC relies on the cartridge/expansion memory area, it is only compatible in 32K mode.
** Extended Colour BASIC is required and 32K is recommended.

The DMMC board has the same dimensions as an original Dragon Data DragonDOS board, this means that with minor modification to the DragonDOS case the DMMC can be fitted.

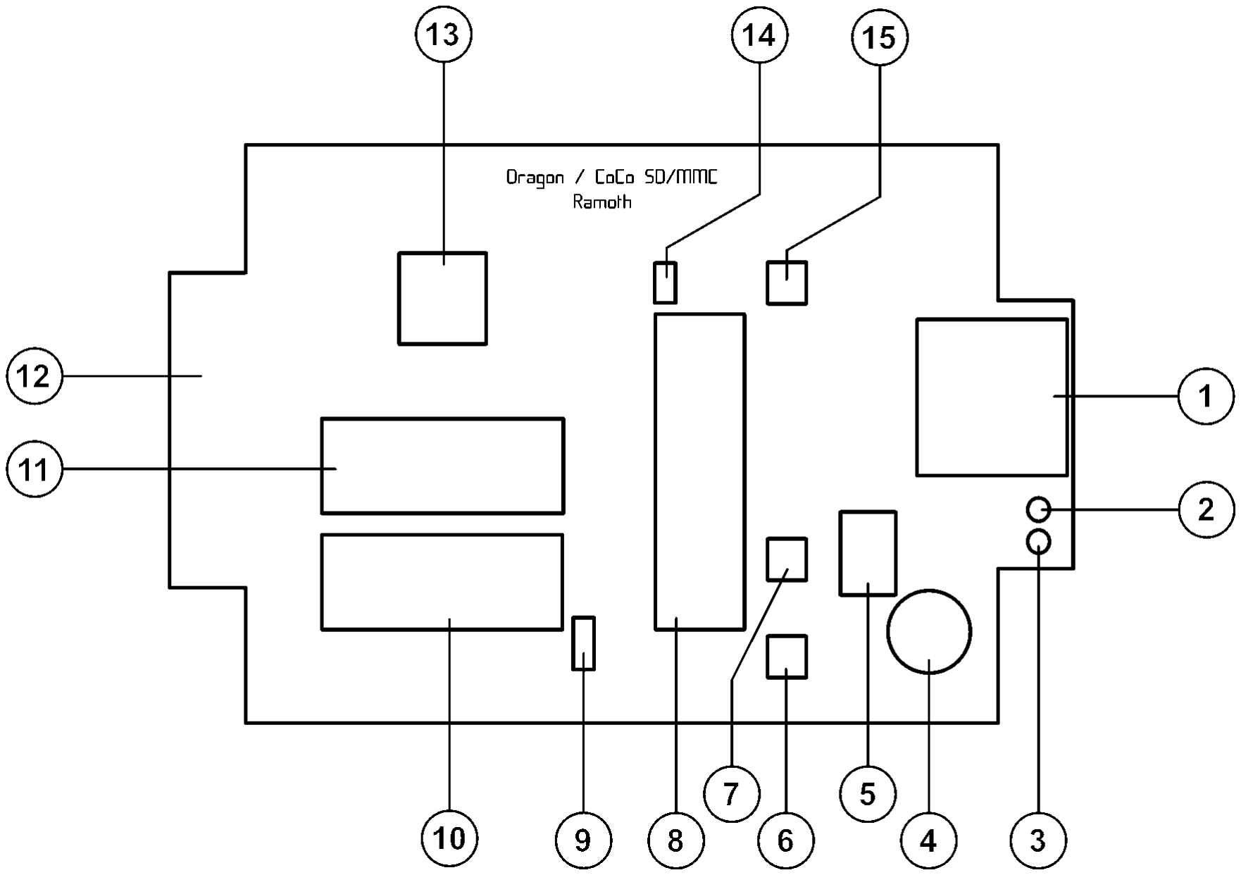
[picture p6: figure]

KEY

1. SD/MMC Card Slot
Insert SD or MMC card here!
2. Red LED
Lit when DragonMMC board being accessed
3. Green LED
Lit when MMC/SD card being accessed.
4. Real Time Clock Battery
Replace with CR1220 or equivalent.

5. Real Time Clock
Provides timekeeping for the host computer and allows files to be correctly timestamped.
6. Snap Shot Button
Accesses the NMI menu, allows you make and load snapshots of the active RAM state.
7. AVR Reset Button
Resets the AVR microcontroller.
8. AVR
Microcontroller that reads and writes the SD card and clock. Has embedded firmware to read and write a FAT/FAT32 Filesystem and convert it into a format that can be used by the host computer.
9. Jumper 2
Write protect jumper for EEPROM / FLASH holding 6809 firmware (DEV ONLY)

10.EEPROM
Holds the 6809 firmware for both the Dragon & CoCo

11.SRAM
Holds mirrored copy of Dragon & DragonMMC ROMs to allow them to be patched, without any modification to originals, cartridge images are also loaded in here

12.Cartridge Edge Connector
Plugs into the computers cartridge slot.

13.CPLD
Handles the interface between the BUS of the 6809 and the AVR. Also does the address decoding for the ROM and RAM, captures writes to the SAM so they can be saved in snapshots.

14.CPLD Program Jumper
Allows in circuit programming socket of the AVR to update bootloader. (DEV ONLY)

15.Force Cold Reset Button
Pressing the Force Cold Reset Button whilst pressing the computers reset button will perform a cold reboot when running ROM (cartridge) images.

CHAPTER ONE

GETTING THE SHOW ON THE ROAD

Connecting Your DMMC Interface

Please ensure that before inserting or removing anything in the cartridge slot that the computer is switched off. Failure to do so may damage both the DMMC and your computer.

Connect your computer to the TV/monitor as normal. Before switching on the computer, insert the DMMC interface into the cartridge slot with the label facing upwards (chips facing up if not in a case). When inserted the DMMC should be flat and level, if using the DMMC without a case ensure it is supported and cannot be knocked or otherwise moved or permanent damage may result.

The computer screen should first show the usual copyrights messages, followed by DMMC messages confirming the DMMC is connected. If it does not, switch off immediately, check the computer connections and that the DMMC is inserted into the cartridge slot correctly. The copyright messages should be followed by OK and the usual cursor.

It’s About Time

The DMMC contains a real time clock (RTC) which allows files saved on the computer onto the memory card to be correctly timestamped. The RTC can also be displayed at boot time and used in BASIC.

The RTC can be displayed from BASIC:-

PRINT MGETDT$
2017-04-01 11:26:57

To get the most from the DMMC, set the clock to the correct time using the format: MSETDT “YYYY-MM-DD hh:mm:ss”

MSETDT “2017-04-02 10:27:00”

Note: you must use a leading zero for values less than 10!

The MGETDT$ function can also be used in a program:-

10 DT$= MGETDT$
20 PRINT “CURRENT DATE AND TIME IS:” 30 PRINT DT$

Setting Up A New Memory Card

The DMMC takes a standard full sized MMC, SD and SDHC cards and has been tested with multiple quality brands (SanDisk etc.), sizes and speeds. Larger capacity SD cards are aimed at fast modern equipment with multimedia in mind, if you are experiencing any issues, with reading or writing to the memory card, try a 4GB or less SD/MMC card (not SDHC or SDXC).

The use of mini and micro cards in adaptors is not recommended.

Don’t forget: Dragon and CoCo disk images and especially cassette images are tiny in comparison to modern storage needs, so 1GB can be overkill.

Format the memory card using FAT or FAT32 and it’s ready to go, pop on your favourite disk (DSK / VDK), cassette images (CAS) or cartridge images (ROM) on and get ready to load your favourite software in seconds.

Due to the limitations of the Dragon screen vs a modern computer, it’s recommended that the amount of files in a folder is limited to maintain usability (ideally < 255). This can be done by dividing games etc. into sub folders, for example by publisher (e.g. DRAGDATA) or alphabetically (e.g. A).

What’s On My Memory Card?

Insert your memory card into the card slot with the label facing up. As the DMMC supports hot swapping of memory cards this can be done with the DMMC on or off.
The command CAT will list files and folders in a directory on the memory card.

CAT

The full title of a file is in the form of a short filename type (8.3):
filename.filetype
where filename is the user-assigned filename (up to 8 characters) and filetype is a code (up to 3 characters) used to distinguish types of files.

Whilst the DMMC can load/save to any file type is it recommended that the following file extensions are used to distinguish different files:-

BAS | BASIC programs saved direct to memory Card (MSAVE)
BIN | Machine Code programs/data saved direct to memory Card (MSAVE)
CAS | Cassette (emulator) images
CCO | CoCo BASIC or Machine Code programs saved direct to the memory Card (MSAVE)
CCC | CoCo cartridge (ROM) Image
DGN | Dragon BASIC or Machine Code programs saved direct to the memory Card (MSAVE)
DSK | CoCo Floppy Disk Image.
ROM | Dragon cartridge (ROM) Image
VDK | Dragon Floppy Disk Image.

CAT can also be used with filenames and wild card characters to limit the display of the files.

CAT
MY.CAS
CUTHBERT.CAS
MYDISK.VDK
MYPROG.CAS
RAILRUN.ROM

To look for any .ROM files in the current directory the * wild card can be used:-

CAT “*.ROM”
RAILRUN.ROM

The ? (question mark) can be used to match any single character:-

CAT “?Y.CAS”
MY.CAS

Directories are distinguished from files by ‘<’ and ‘>’ around the name:

CAT
<.>
<..>
<GAMES>
<UTILITY>

Too many files listed to fit on the screen? Try the CATP command which will page the results.

The command CWD can be used to change (the working) directory on the memory card, when entering directory names the ‘<’ and ‘>’ around the name should be omitted:-

CWD “GAMES”

To move into the parent directory use .. as the directory name:-

CWD “..”

You can also move to through multiple directories at the same time:

CWD “GAMES/BLABY”

Finding your current folder is easy with the WD$ function:

PRINT WD$
0:/GAMES/BLABY

The “0:” shows that the current memory card is drive 0, as there is only one card slot the drive is always 0

To go back to the root directory, you can specify “/”:-

CWD “/”

Long File Names

Whilst the Dragon (and CoCo) is limited to short filenames (8.3 as above) on the memory card modern computers support long filenames. Any long filenames on the memory card will be shortened to fit the short filename scheme.

When shortened on a modern computer, a ‘~’ (tilde) is used in short version of the name for long filenames (to fit 8.3). However the Dragon character set does not have the “~” character, so instead the inverse “↑” is used. The inverse “↑”cannot be entered on the Dragon or CoCo keyboards, so “↑” (up arrow) is used in replace of the inverse “↑” when entering file and directory names, for example:

Starship Chameleon.CAS | Modern long filename
Starsh~1.CAS | Displayed as short filename on a modern computer
STARSH↑1.CAS | As displayed by the CAT command
STARSH↑1.CAS | As entered from the Dragon keyboard

How this is used on the Dragon:-

CAT
STARSH↑1.CAS
MTAPERUN “STARSH↑1.CAS”

Due to the long filename support and the Dragons (now) limited keyboard, files on the memory card containing “^” (caret symbol) in them are not supported.

### CHAPTER TWO

LOADING UP

This chapter covers how to load and use emulator cassette, cartridge and disk images on your real Dragon or CoCo.

Loading Cassette Images (CAS)

The quickest and easiest method to load cassette images is with the MTAPERUN command:-

MTAPERUN “CUTHBERT.CAS”

This command performs the following actions:
a) turns on tape emulation
b) mounts the specified file into the virtual cassette recorder as read only
c) loads the first program from the emulated tape image (CUTHBERT.CAS in this example).
d) automatically executes the program, BASIC or machine code.

When using cassette images the physical relay in the computer will still click for the cassette recorder motor as if was loading a physical cassette.

Many cassette programs do not expect the disk system to be present, to improve compatibility it’s recommend that disk emulation is turned off (MDISK OFF) when not being used.

An alternative method is to use the cassette emulation mode, when enabled all BASIC cassette commands, are directed to the virtual cassette recorder and the mounted cassette image (CAS file).

MCAS

Enables cassette emulation mode, so all tape related commands go to the virtual recorder instead of the physical tape port.

MMOUNTR “BUZZARDB.CAS”

This mounts the tape image BUZZARDB.CAS in the virtual recorder in read only mode.

If you don’t know what type of program the cassette image is use the CFTYPE function. 0 = BASIC, 1 = ASCII data/BASIC, 2 = Binary data or Machine Code, 255 = Invalid

PRINT CFTYPE
2
CLOADM

Load the program using the normal cassette commands. Putting this all together we have:

MCAS
MMOUNTR “BUZZARDB.CAS”
PRINT CFTYPE
2
CLOADM

When loading, the computer will behave as if it’s loading a real cassette, so the computer will click and F with the program name will appear in the top left hand corner of the screen. The difference is that the program will load in seconds instead of minutes.

If you need to rewind the virtual recorder back to the beginning of the beginning of the tape image use:

REWIND

When finished with the cassette image it can be unmounted:

MMOUNTC

Loading Cartridge Images (ROM/CCC)

The DMMC allows use of cartridge image (ROM or CCC) files and will load them into the same memory space as a normal cartridge, to become a virtual cartridge that will behave in the same manner as a real cartridge. The most common cartridges are auto starting and they are loaded using MCARTLOADA :

CAT
RAILRUN.ROM
MCARTLOADA “RAILRUN.ROM”

This will load the RAILRUN.ROM image into memory and auto start it.

To load a cartridge image into the virtual cartridge but not auto start it, use MCARTLOAD:

CAT “*.ROM”
MYCART.ROM
MCARTLOAD “RAILRUN.ROM”

Note:- Loading a cartridge image will overwrite the MMC memory, so all MMC functions and commands (inc snapshot) will no longer be available, until the next cold boot.

Pressing the Force Cold Reset Button whilst pressing the computers reset button will perform a cold reset when running ROM (cartridge) images.

Using Floppy Disk Images (DSK/VDK)

The DMMC will emulate DragonDOS (Dragon) or RSDOS (CoCo) systems with 4 virtual floppy disk drives, into which 4 disk images can be mounted. At boot time the DMMC determines which computer it’s being used on (Dragon or CoCo) and auto enables the appropriate disk system. Enabling the DOS system (the equivalent of connecting the DOS cartridge with disk drives) will cause the computer to do a cold boot, so any programs etc. in memory will be lost. Enable DOS by typing the following,

MDISK ON

The computer will now perform a cold boot showing the usual copyright and DMMC messages plus the DOS message, you now have 4 disk drives at your disposal that can be used in exactly the same way as a real DOS system but with the benefit of access to the memory card.

The DMMC command to mount (or insert) a disk image into a drive is:
MDISKI driveno,”filename”
Where driveno is the drive number (1-4 for Dragon / 0-3 for CoCo) and filename is the name of the disk image on the memory card. The DMMC uses the file extension on the disk image to determine the disk format, so DSK should be used on CoCo format disks and VDK should be used on Dragon format disks, although the DMMC allows the use of both on either computer.

Let’s mount (insert) a disk image into drive 1:-

CAT
MYDISK.VDK
MDISKI 1,” MYDISK.VDK”

Now we have a disk in drive 1, it can accessed using the normal DOS commands, such as directory listing and loading a BASIC program:

DIR 1
MYPROG.BAS
LOAD “MYPROG.BAS”

Having 4 disk drives available can make it difficult to keep track of what disk images are mounted, so use the following:-

MDISKL

This will list the 4 disk drives and the names of the disk images in use in them, in our example it will show MYDISK.VDK in disk drive 1.

Finished with a disk and want to pop it out of the drive?
MDISKO driveno
where driveno is number of the drive you wish to unmount the image on.

MDISKO 1

Blank disk images can also be created on a Dragon like so:

MDISKC 1,"NEWDRAG.VDK"
DSKINIT 1,2,40

On a Coco:

MDISKC 1,"NEWCOCO.DSK"
DSKINI1

DOS emulation will remain permanently enabled until it is turned off, even if the computer is turned off, DOS emulation can be turned off with:-

MDISK OFF

Disabling the DOS system with MDISK OFF (the equivalent of removing the DOS cartridge with disk drives) will cause the computer to do a cold boot, so any programs etc. in memory will be lost.

The currently mounted virtual disks are saved to the binary SETTINGS file in the root directory of the memory card. This means that the disks will remain mounted even after computer has been turned off/on.

Booting FLEX

As the FLEX operating system needs 64K and uses the same memory space as the DMMC, it requires an additional driver. To allow booting of FLEX please download the latest FLEX unities.
http://www.archive.worldofdragon.org/index.php?title=DragonMMC_SDCard
Copy the download files DISKMMC.DGN and FLEXBOOT.DGN onto your SD/MMC card along with the flex disk image you want to boot e.g. FLEXBOOT.VDK.

Mount the FLEX disk you wish to boot, into the first drive and then run the included DISKMMC.DGN and FLEXBOOT.DGN utilities in order:

MDISKI 1,"FLEXBOOT.VDK"
MLOAD "DISKMMC.DGN"
MLOADA "FLEXBOOT.DGN"

Note: at present there are no native Flex utilities for manipulating disk images so any images you wish to use, must also be mounted in the other virtual drives before booting.

Don’t forget “FLEX IS BEST”.

### CHAPTER THREE

SNAPPY DRAGON MMC

The DMMC snapshot button allows you to save and load ‘snapshots’. The snapshot facility saves the current state of the computer and when loaded back in it will return the computer back to exact same point it was pressed. So if you’ve been adventuring in the forest for hours but don’t want to lose all that effort, don’t worry snapshot it.

The snapshot facility relies on the NMI interrupt and memory allocated to the cartridge slot, Because of this cartridge images (ROM/CCC) and certain software do not support the snapshot facility.

As default snapshots are saved to the root directory of the memory card, this can be changed using the CWDS command and displayed with the variable SD$.

MKDIR “0:/DRAG-SSD”
CWDS “0:/DRAG-SSD”
PRINT SD$
0:/DRAG-SSD
CWD SD$

This will create the snapshot directory, set the snapshot directory, display its current setting and change directory the snapshot directory.

Pausing, Saving and Loading

Let’s try snapshot with the classic Hello World program

10 PRINT “HELLO WORLD”
20 GOTO 10
RUN

This will enter a program and set it running forever but now press the Snapshot button on the DMMC. This will have the effect of pausing the normal execution of the computer and bring up the Snapshot menu at the bottom of the screen.

When the Snapshot is activated the computer will be put back into normal text mode. In some cases, the top part of the screen will look corrupted; this is normal and just residual data from the running program.

Press the [X] key to exit the menu, this will un-pause the running program and allow it to continue as if nothing happened.
Press the Snapshot button again to bring up the menu and press the [S] key to save the snapshot. Enter a filename of MYSNAP for the snapshot (up to 8 characters is allowed), there’s no need to add the extension it’s added automatically (SSD for Dragon snapshots and SSC for CoCo). Press the [X] key to exit the menu and the program will carry on running.

Press the [BREAK] key to stop the program and type NEW to clear the Hello World program from memory.

Let’s restore the Hello World program back to its running state, this can be done through the BASIC command MLOADS or through the Snapshot menu. In BASIC enter the following:-

CWD SD$
MLOADS “MYSNAP.SSD”

The Hello World program is restored back in an instant to its original running state! Let’s clear the program again, press the [BREAK] key to stop the program and type NEW.
Press the Snapshot button to bring up the menu and press the [L] key to load a snapshot. Enter the filename of MYSNAP for the previously saved snapshot, the snapshot will now load and again return the Hello World program to its running state.

You have now successfully paused, saved and loaded your first snapshot.

Booting and Resetting

The snapshot button also has the convenient feature of being able to perform a reset (warm reset) or the equivalent of a power cycle (cold reset).

Press the Snapshot button to bring up the menu and press the [W] key to perform a Warm reset, the equivalent of pressing the reset button.

Press the Snapshot button to bring up the menu and press the [C] key to perform a Cold reset, equivalent to when the power is turned on.

If an auto starting ROM image is loaded then the computers reset button and DMMC snapshot buttons will not allow you to exit to program, to reset the computer press the force cold reset button at the same time as the computers reset button.

### CHAPTER FOUR

GOING NATIVE

In addition to supporting emulator files the DMMC has many BASIC commands and functions that allow you create your own CAS files and incorporate the DMMC into your own programs.

Making Your Own Cassette Image (CAS)

As well as being able to load CAS files generated from original cassettes, with the MCAS tape emulation mode the normal CSAVE and CSAVEM will allow you to save directly to a CAS file.

Let’s try saving a BASIC program again using the classic Hello World program

10 PRINT “HELLO WORLD”
20 GOTO 10

Enable cassette emulation mode, to direct all tape related commands go to the virtual recorder:

MCAS

Creates and mount a CAS file to save our Hello World program in the current directory:

MMOUNTW “HELLOW.CAS”

Save the program using the standard CSAVE command:

CSAVE “HWORLD”

View the CAS file on the card:

CAT “HELLOW.CAS”

Before we load the program back in, we need to close the virtual tape, mount it for reading and clear the program from memory:

MMOUNTC
MMOUNTR “HELLOW.CAS”
NEW

Ready to load the program back in from the CAS:

CLOAD

When loading the computer will behave as if it’s loading a real cassette, so the computer will click and “F HWORLD” will appear in the top left hand corner whilst loading.

Now we’ve finished loading we can take the take the virtual cassette out of the virtual tape recorder (MMOUNTC) and run our freshly loaded Hello World program:

MMOUNTC
RUN

You can now load and save your own BASIC programs, into a CAS file. As the MCAS and MMOUNTx commands allow the use of the standard BASIC tape commands further examples on how to use load and save to cassette can be found in the original BASIC manual.

What’s In a Directory

The CAT and CATP commands allow you to see what files and directories are in the current directory but there are functions available to return strings with the directory listing.

FINDFIRST$ finds the first file/directory in the current folder

PRINT FINDFIRST$
<.>

To get the next file in the directory use the FINDNEXT$ function

PRINT FINDNEXT$
<..>

Subsequent calls made to FINDNEXT$ returns the next file/directory in the current folder, when no more files are found FINDNEXT$ returns an empty string.
Pattern matching (wildcards) can also be used with FINDFIRST$ in the same manner as CAT

PRINT FINDFIRST$ “*.CAS”
MY.CAS
and
D$ = FINDFIRST$ “*.CAS”
PRINT D$
MY.CAS

Now we can put this together to write a program that displays all the CAS files in the current directory:

10 PRINT “CURR DIR: “ WD$
20 PRINT FINDFIRST$ “*.CAS”
30 N$=FINDNEXT$
40 IF N$=”” GOTO 70
50 PRINT N$
60 GOTO 30
70 PRINT “***DONE***”

Saving In DMMC Native Format

Let’s try saving a BASIC program with the classic Hello World program

10 PRINT “HELLO WORLD”
20 GOTO 10
MSAVE “HWORLD.BAS”

This will create the file HWORLD.BAS on the memory card, containing the Hello World program.

If auto .BAK creation is enabled when using MSAVEM and HWORLD.BAS already exists it is renamed to HWORLD.BAK and if HWORLD.BAK already exists it is deleted. If auto .BAK creation is not enabled when using MSAVEM and the file HWORLD.BAS already exists the file will not be overwritten and the command will error. See MSETCFG command for details on how to set this.

When saving BASIC programs it is recommend that the file extensions of .BAS, .DGN or .CCO are used.

Now we can clear the program and reload it:

NEW
MLOAD “HWORLD.BAS”
LIST
10 PRINT “HELLO WORLD”
20 GOTO 10

### CHAPTER FIVE

TROUBLESHOOTING

This chapter gives help on loading cassette images and the use of DOS. Also don’t forget to keep up to date with new firmware etc. at the following address:

http://www.archive.worldofdragon.org/index.php?title=DragonMMC_SDCard

THE PROBLEM WITH CAS

Over the years CAS files have been produced with various tools in different states of development and this has resulted in CAS files of varying quality. As the DMMC uses the original cassette loading routines, any CAS files with faults won’t load. When using emulators like XROAR many of these problems aren’t apparent as it can fix some issues ‘on the fly’.

Below are some guidelines on how get the CAS files loaded.

First Steps

It may seem obvious but the first thing to try is a different CAS file for the same title. Many titles have different CAS files available and they may have been created at different times with different software and different sources, so there’s a good chance that another CAS file will work.

Typically cassette programs do not expect the disk system to be present, so turn disk emulation off with:

MDISK OFF

Along with the disk system not being present some software titles rely on the computer being in a fresh state, where the first command(s) entered after a cold boot are to load the software. If using AUTOEXEC to run a program at boot time, such as the ‘Explorer’ prevent it from running by pressing the space bar at boot time or to permanently disable it, with (show clock at boot time):

MSETCFG 16
Or with no clock display at boot time:

MSETCFG 0
Perform a cold boot (power off/on) for the change to take effect.

Try both methods of loading CAS files, (MCAS and MTAPERUN) straight after turning on with no autoexec, e.g.:

MCAS
MMOUNTR “BUZZARDB.CAS”
CLOADM
and
MTAPERUN “BUZZARDB.CAS”

New Life for CAS

The XROAR emulator has the ability to ‘regenerate’ CAS files, fixing a number of common issues along the way. For this you will need a copy of XROAR (www.6809.org.uk) installed with a BASIC ROM for your chosen computer.

Once you have setup XROAR with your chosen ROM, we’ll create a new shortcut to set the options to re-write the loaded CAS image into a new file:
- Browse to the folder containing XROAR.
- Right click on the XROAR executable and select ‘Create Shortcut’.
- Right click on the new shortcut and select rename.
- Rename the shortcut to ‘xroar.exe write CAS’
- Right click on the shortcut and select Properties.
- In the Target: test box add the following: ‘ -tape-rewrite’ to the end of the text. The end of the Target text will now look like:
xroar.exe -tape-rewrite
- Click OK when done

Now the shortcut has been created we can now regenerate the CAS file:
- Double click on the shortcut ‘xroar.exe write CAS’ to open XROAR.
- Select the CAS file you wish to regenerate: File -> Cassette -> Input Tape..
- Enter the filename and select the location you wish to save the new CAS file to: File -> Cassette -> Output Tape..
- Use CLOAD or CLOADM to load your software.
- Once loaded quit XROAR.
- You should now have a new CAS file ready to load on your computer with the DMMC.

If you are comfortable using the Windows command line the regeneration of the CAS file can be done one command line:-

xroar -tape-rewrite -timeout-motoroff 1 -run <input-file> -tape-write <output.cas> -ui null -ao null

e.g.

xroar -tape-rewrite -timeout-motoroff 1 -run cranky.cas -tape-write NEWcranky.cas -ui null -ao null

THE PROBLEM WITH DOS

DragonDOS has been known to be buggy for years, with Dragon User May 1985 listing over 15 known problems and bugs in DragonDOS 1.0. Whilst DMMC is built on version 1.3, bugs still do remain and are probably more likely to occur if using all the disk drives on the DMMC, given that most users in the day would have only had one or two disk drives.

For example, one bug found during DMMC testing is that when a file is copied (using COPY) from drive 4 to any other drive it will corrupt the destination drive. It is therefore recommended that you regularly backup important disk images to a modern computer in case of disaster when using DragonDOS or RSDSOS.

APPENDIX A

DRAGON MMC COMMANDS

CAT

CAT “pattern”

The CAT command lists the files (and folders) on memory card in the DMMC.
CAT | List all files in the current directory.
CAT “..” | List all files in the parent directory.
CAT “./GAMES” | List all files in the GAMES sub directory.
CAT “/” | List all files in the root directory.

The CAT command also accepts the ( * and ? ) wildcard characters.
* | Matches zero or more characters
? | Matches any single character
CAT “*.CAS” | List all the files in the current folder that end in “.CAS”
CAT “A?” | List 2 character files in the current folder that start with
“A” and any second character. CAT “DISK/*.VDK” List all files in the subfolder “DISK” that end in”.VDK”

Directories are distinguished from files by ‘<’ and ‘>’ around the name:
CAT
<.>
<..>
<GAMES>

If there are less than 256 files and folders returned, folders will appear before files and each will be alphabetically sorted. If more than 256 items are present no sorting will occur due to
memory limitations.

See Also:-
CATP
Long File Names (Chapter 1)

CATP

CATP “pattern”

The CATP command lists the files (and folders) on the memory card in the DMMC. If the number of files exceeds what can be displayed on screen the results will be paged.

See CAT command for examples.

CWD

CWD “dirname”

Changes the current directory on the memory card to the specified directory.

The command CWD can be used to change (the working) directory on the memory card, when entering directory names the ‘<’ and ‘>’ around the name should be omitted:-
CWD “GAMES”

To move into the parent directory use .. (dot)(dot) as the directory name:-
CWD “..”

You can also move to through multiple directories at the same time:-CWD “GAMES/BLABY”

To go back to the root directory, you can specify “/”:-
CWD “/”

The CWD command can also be used with strings:-A$=”GAMES”
CWD A$

CWDS

CWDS “dirname”

Sets the directory where snapshots are saved, by default the root folder on the card is used.

The directory specified must exist and be a full path. If the directory specified does not exist, it will default back to the root folder.

Dragon and CoCos have separate folders and must be set on each computer.

CWDS “/DRAG-SSD”
PRINT SD$
0:/DRAG-SSD

See Also:-
SD$

HELP
HELPX

The HELP command displays the version text of the DMMC and sub components.

HELP

The HELPX command displays same as HELP plus the compile dates for AVR firmware and AVR bootloader.

HELPX

See Also:-
VER (function)

MCARTLOAD
MCARTLOADA

MCARTLOAD “filename”
MCARTLOADA “filename”

Load the specified cartridge ROM/CCC image file into the MMC card ram in the $C000-$FFEF area (cartridge slot memory).

MCARTLOADA resets the machine after loading the cartridge image and connects the Q clock to the FIRQ line on the cartridge port. This allows the use of auto-starting cartridge images such as the majority of games.

Note Loading a ROM image will overwrite the MMC ROM, so MMC functions will no longer be available.

MCAS

The MCAS command enables virtual cassette recorder mode, this allows the use of emulator .CAS files as if it was a normal tape.

When enabled all BASIC cassette commands (CLOADM etc.) are directed to the virtual DMMC cassette drive instead of the physical tape drive of the computer.

MCAS
MMOUNTR “GAME.CAS”
CLOAD

Most commercially released software doesn’t expect to run on computer with DOS. It’s recommend that disk (DOS) emulation is turned off (see MDISK OFF) if not specifically needed when loading cassettes.

The MCAS command copies the upper 32K from the ROM into the 32K of RAM on the MMC board and patches it so that cassette based rom calls are directed to the MMC.

See Also:-
MMOUNTC
MMOUNTR
MMOUNTW
MDISK OFF

MDELETE

MDELETE “filename”

Deletes the specified file from the memory card, you will be prompted (Y/N) before deletion.

MDELETE “MYPROG.DGN”
ARE YOU SURE (Y/N)
OK

MDISK ON

Turn on disk emulation for the current platform and do a cold reset.

See Also:-
MDISKL
MDISKO
MDISK OFF
MSETCFG

MDISK OFF

Turn off disk emulation for the current platform and do a cold reset.

See Also:-
MDISKL
MDISKO
MDISK ON
MSETCFG

MDISKC

MDISKC driveno,”filename”

Creates a blank disk image with the filename in drive driveno (1-4 for Dragon / 0-3 for CoCo), can be used for VDK and DSK images. Disk will require formatting before use (i.e. DSKINIT or DSKINI).

MDISKC 1,”NEWDISK.VDK”
DSKINIT 1,1,40
CAT
NEWDISK.VDK
MDISKL
1: 0:/VDK/NEWDISK.VDK
2:
3:
4:
OK

See Also:-
MDISKI
MDISKO

MDISKI

MDISKI driveno,”filename”

Mount disk image filename in drive driveno (1-4 for Dragon / 0-3 for CoCo).

CAT
MYDISK.VDK
BACKUP.VDK
MDISKI 1,” MYDISK.VDK”
MDISKI 3,” BACKUP.VDK”

When using disk images the file extension for the images should be DSK for CoCo format and VDK for Dragon format. .

Notes on floppy disk Images:
DSK Floppy disk images (normally CoCo) will be treated as raw sector dumps so the virtual geometry will be guessed from the file size,
VDK Floppy disk images (normally Dragon) have a header that defines the geometry so it that used to determine the disk format.

See Also:-
MDISKC
MDISKL
MDISKO
MDISK OFF
MDISK ON

MDISKL

List mounted disk images in the 4 virtual floppy disk drives.

CAT
MYDISK.VDK
BACKUP.VDK
MDISKI 1,” MYDISK.VDK”
MDISKI 3,” BACKUP.VDK”
MDISKL
1: 0:/VDK/MYDISK.VDK
2:
3: 0:/VDK/BACKUP.VDK
4:
OK

See Also:-
MDISKI
MDISKO

MDISKO

MDISKO driveno

Dismount disk image from driveno (1-4 for Dragon / 0-3 for CoCo).

Unmount the disk image in virtual drive 3:-
MDISKO 3

See Also:-
MDISKI
MDISKL

MFILEC

MFILEC “file1”, “file2”

Copies file1 to file2.

Create a copy of a file:-
CAT
MYPROG.BAS
MFILEC “MYPROG.BAS”,”COPYPROG.BAS” MYPROG.BAS
COPYPROG.BAS

MFILER

MFILER “file1”, “file2”

Rename (or move) file1 to file2.

Rename a file:-
CAT
MYPROG.BAS
MFILER “MYPROG.BAS”,”NEWPROG.BAS” CAT
COPYPROG.BAS

Move a file to the parent folder:
MFILER “MYPROG.BAS”,”../MYPROG.BAS”

MKDIR

MKDIR “dirname”

Creates the specified directory.

Create a directory in the current folder:-
MKDIR “GAMES-A”

Absolute and relative paths can also be specified:-MKDIR “/GAMES-B”
or
MKDIR “../GAMES-C”

MLOAD
MLOADA
MLOADC

MLOAD “filename”
MLOAD “filename”, location
MLOADA,”filename”
MLOADC “filename”
Load the previously saved BASIC or machine code program from the memory card. MLOADA will attempt to automatically run a BASIC program once loaded.

MLOAD “DRAGPROG.BAS”

The location is the address to load a machine code program into memory.

MLOAD “MACH.BIN”,1000

MLOADC operates as MLOADA but first clears any active program and returns the machine to its power on state.

See Also:-
MSAVE
MSAVEM

MLOADS

MLOADS “filename”

Loads a previously saved system snapshot: MLOADS “GAMESNAP.SSD”

See Also:-
CWDS
SD$

MMIRROR
MMIRORA

MMIRROR “filename”
MMIRRORA “filename”

Mirrors tape data as it’s loaded into the computer to a CAS format file.
MMIRROR "FILENAME.CAS"

After the MMIRROR command is entered, type CLOAD or CLOADM to load the program and let the tape load as normal.

Once the program has loaded correctly, press the snapshot button on the DMMC, this will finalise the mirror/copy process.

MMIRORA works like MMIRROR but just keeps reading the tape, using block in and echoing to the MMC, useful if you have a C90 full of stuff you want to archive all in one go.

MMOUNTC

Unmounts the currently open (.CAS) cassette image file, this will prevent any further reading or writing to the image file until it mounted again.

MCAS
MMOUNTW “MYPROG.CAS”
CSAVE “MYPROG3”
MMOUNTC

See Also:-
MCAS
MMOUNTR
MMOUNTW
REWIND

MMOUNTR

MMOUNTR “filename”

Mounts an existing cassette image file (.CAS) into the virtual DMMC tape recorder, in read only mode, preventing accidental overwriting.

MCAS
MMOUNTR “MYPROG.CAS”
CLOADM

See Also:-
MCAS
MMOUNTC
MMOUNTW
REWIND

MMOUNTW

MMOUNTW “filename”

Creates and mounts a cassette image file (.CAS) into the virtual DMMC tape recorder in write only mode. This allows the saving of programs and data to a virtual cassette file.

MCAS
MMOUNTW “MYPROG.CAS”
CSAVE “APROG”
MMOUNTC

See Also:-
MCAS
MMOUNTC
MMOUNTR
REWIND

MSAVE

MSAVE “filename”

The MSAVE command may be used to save BASIC programs directly to the memory card.

MSAVE “MYPROG2.BAS”

Will create a file MYPROG2.BAS on the memory card, containing the BASIC program currently in memory.

If auto .BAK creation is enabled when using MSAVEM and MYCODE.BAS already exists it is renamed to MYCODE.BAK and if MYCODE.BAK already exists it is deleted.
If auto .BAK creation is not enabled when using MSAVEM and the file MYCODE.BAS already exists the file will not be overwritten and the command will error.

When saving BASIC programs it is recommend that the file extensions of .BAS, DGN or .CCO are used.

See Also:-
MLOAD
MSAVEM
MSETCFG

MSAVEM

MSAVEM “filename”, start, end, entry

The MSAVEM command may be used to transfer machine code programs (or other binary data) directly to the memory card.

Note the filename is used as specified, and no extension is added. Files are saved in the same format as files on a DragonDOS disk.

MSAVEM “MYCODE.BIN”,2000,5000,4000

Will create a file MYCODE.BIN on the memory card containing the sequence of bytes from memory start-address 2000 to end-address 5000. When this file is loaded, the default EXEC address will be set to 4000.

If auto .BAK creation is enabled when using MSAVEM and MYCODE.BIN already exists it is renamed to MYCODE.BAK and if MYCODE.BAK already exists it is deleted.
If auto .BAK creation is not enabled when using MSAVEM and the file MYCODE.BIN already exists the file will not be overwritten and the command will error.

When saving machine code programs it is recommend that the file extensions of .BIN, .DGN or .CCO are used.

See Also:-
MLOAD
MSAVE
MSETCFG

MSETCFG

MSETCFG flags
MSETCFG flags , <platform>

Set the configuration flags for the interface, the parameters are bitwise and of the following values.

A valid platform is:-
0 | System
1 | Dragon
2 | CoCo

If no platform is specified then the current platform (Dragon or CoCo) is assumed. Valid flags for the System (DMMC) platform:-
Hex Dec Purpose
&H80 128 Enable firmware updating from the memory card the next time it is rebooted. **
&H04 4 Enable auto .BAK creation when using MSAVE . When attempting to create a file with MSAVE"TEST.BAS", if TEST.BAS already exists it is renamed to TEST.BAK and if TEST.BAK already exists it is deleted.
&H02 2 Disable the display of files beginning with ‘ ._’ (dot)(underscore) or ‘ _ ‘(underscore). This allows hiding of Apple Mac meta data files.
&H01 1 Enable debugging information to be sent to the AVR’s TTL serial port. This is really only of use for firmware development, and *WILL* slow down the interface!
** The firmware update flag is reset after a successful firmware update.

Continued…

MSETCFG continued

Valid flags for the Dragon and CoCo computers:-
Hex | Dec Purpose
&H40 64 | Enable execution of the “AUTOEXEC” file, this should be a
BASIC program saved with MSAVE.
&H20 32 Enable DragonDOS (Dragon) or RSDOS (CoCo) emulation using disk images. Also set by MDISK ON / MDISK OFF
&H10 16 | Enable the display of real time clock data and time at boot up.
&H08 8 | Enable the display of the firmware compile date at start-up.

Set AUTOEXEC off, DOS on (32) and RTC display off
MSETCFG 32

Set AUTOEXEC on (64), DOS off and RTC display on (16) MSETCFG 80
Or in Hex:
MSETCFG &H50

Disable the display of files starting with ‘ ._ ‘ MSETCFG 2,0

Enable the display of files starting with ‘ ._ ‘ MSETCFG 0,0

See Also:-
MGETCFG
MSETCFGC
MSETCFGS

MSETCFGC
MSETCFGS

MSETCFGCflags
MSETCFGC flags , <platform>
MSETCFGC will clear any bit that is set in the config byte, and leave alone any that is clear, i.e MSETCFGC performs a bitwise OR operation.

MSETCFGS flags
MSETCFGS flags , <platform>
MSETCFGS will set any bit that is set in the config byte, and leave alone any that is clear, i.e MSETCFGS performs a bitwise AND NOT operation.

Assume the system configuration byte is currently &H03 (0000 0011)

Command | Current Value | Value After
MSETCFGS &H80,0 | &H03 (0000 0011) | &H83 (1000 0011)
MSETCFGC &H01,0 | &H03 (0000 0011) | &H02 (0000 0010)

MSETDT

MSETDT “YYYY-MM-DD hh:mm:ss”

Set the real time clock, used for date stamping files.

Format MUST be:-
YYYY | Year 2000-2099
MM | Month 01-12
DD | Day of month 01-31
hh | Hour in 24 hour format 00-23
mm | Minutes 00-59
ss | Seconds 00-59

Setting the date and time:-
MSETDT “2017-04-02 10:27:00”

Note: that you must use a leading zero for values less than 10!

See Also:-
MGETDT$

MTAPERUN

MTAPERUN “filename”

Turns on tape emulation, mounts the specified file as read-only and loads the first file from the emulated tape. The first program on the image is automatically executed.
Equivalent to MCAS : MRMOUNT “filename” : CLOAD : RUN for basic programs and MCAS : MRMOUNT “filename” : CLOADM for machine code.

NOTE: MTAPERUN does the equivalent of CLEAR 200,ramtop before executing and loading the cassette file (where ramtop is the amount of physical RAM e.g. 16K, 32K).
If you do not want this to happen, use MCAS, MMOUNTR and CLOAD(M) instead.

RETOKC

BASIC commands on the Dragon and CoCo are stored in the memory using ‘tokens’ but the Dragon and Coco use different tokens for the same commands. This means that when a BASIC program is loaded form another platform the resulting program becomes ‘garbled’.

This command, re-tokenizes the BASIC program in memory from Dragon to CoCo. If no equivalent command is available the command is converted into a REM statement.

MLOAD “MYPROG.DGN”
RETOKC
MSAVE “MYPROG.CCO”

See Also:-
RETOKD

RETOKD

Re-tokenize the BASIC program in memory from CoCo to Dragon. If no equivalent command is available the command is converted into a REM statement.

MLOAD “MYPROG.CCO”
RETOKD
MSAVE “MYPROG.DGN”

See Also:-
RETOKC

REWIND

Rewinds the cassette image file (.CAS) loaded into the virtual DMMC tape recorder.

MCAS
MMOUNTR “MYPROG2.CAS”
CLOADM
?FM ERROR
OK
REWIND
CLOAD
OK

See Also:-
MCAS
MMOUNTC
MMOUNTR
MMOUNTW

APPENDIX B

DRAGON MMC FUNCTIONS

Note: Functions ending in $ return a string, all others return an integer.

CFTYPE

Get the file type of the next file on an emulated cassette. 0 = Tokenised BASIC,
1 = ASCII BASIC or ASCII data
2 = Machine code or Binary data
255 = Invalid Header
Note: If an invalid CAS or non-cassette image file is mounted, any value 0-255 could be returned.

Use CFTYPE to identify the type of program (BASIC or Machine Code) before loading:-MCAS
MMOUNTR “MYPROG.CAS”
PRINT CFTYPE
2
CLOADM

CFTYPEE

Get the EXEC address of the next file on an emulated cassette.

MMOUNTR “NERBLE.CAS”
?CFTYPEE
10518

CFTYPEL

Get the load address of the next file on an emulated cassette.

MMOUNTR “NERBLE.CAS”
?CFTYPEL
109

FINDFIRST$

FINDFIRST$ “pattern”

Finds the first file/folder based on the pattern, subsequent calls should be made to FINDNEXT$ Returns an empty string when no files are found.

PRINT FINDFIRST$ “*.ROM”

See Also:-
FINDNEXT$
CAT command

FINDNEXT$

FINDNEXT$

Finds the next file in the sequence started by FINDFIRST$

PRINT FINDFIRST$ “*.ROM”
N$=FINDNEXT$
PRINT N$

Returns an empty string when no more files are found.

If there are less than 256 files and folders present, folders will appear before files and each will be alphabetically sorted. Due to memory limitations if more than 256 items are present no sorting will occur.

MGETCFG

MGETCFG
MGETCFG(<platform>)

Get the configuration flags, see MSETCFG for details. If no platform is supplied then the current platform is assumed (Dragon or CoCo).

A valid platform is:-
0 | System
1 | Dragon
2 | CoCo
255 System enquiry

Get the configuration for the current computer (Dragon or CoCo): ?MGETCFG
80

Get the configuration for the CoCo configuration:
?MGETCFG(2)
16

To confirm which computer the current platform is, MGETCFG(255) can be used, returns 1 for Dragon and 2 for CoCo:
?MGETCFG(255)
1

See Also:-
MSETCFG command

MGETDT$

Returns the current real time clock time in the format as “YYYY-MM-DD hh:mm:ss”.

The RTC can be displayed from BASIC:-

PRINT MGETDT$
2017-04-01 11:26:57

The MGETDT$ function can also be used in a program:-

10 DT$= MGETDT$
20 PRINT “CURRENT DATE AND TIME IS:” 30 PRINT DT$
Or
10 PRINT “CURRENT DATE AND TIME IS:” 20 PRINT MGETDT$

See Also:-
MSETDT

MGETINAME$

MGETINAME$ DriveID

Returns the filename of the mounted disk image on the specified driveid (1-4 for Dragon / 0-3 for CoCo), returns an empty string if no disk is mounted on the specified drive.

PRINT MGETINAME$ 1
0:/VDK/MYDISK.VDK

VER

Return the DMMC firmware version

PRINT VER
NUMBER TBC

NOT YET IMPLEMETED

SD$

Returns the directory name where snapshot files are saved. The default value is the root folder of the memory card.

PRINT SD$
0:/DRAG-SSD

See Also:-
CWDS

WD$

Returns the current directory name.

PRINT WD$
0:/AGAMES
OK

See Also:-
CWD

APPENDIX C

DRAGON MMC MISCELLANEOUS
Everything else you need to know

AUTOEXEC

This useful facility allows the automatic execution (running) of a BASIC program when the computer does a cold boot. This allows you to automatically start your favourite game or menu program etc.

The AUTOEXEC file should be a BASIC program in the root directory of the memory card saved with MSAVE . To run the AUTOEXEC program at boot time ensure the option is enabled with MSETCFG

Set AUTOEXEC on (64), DOS off and RTC display on (16)

MSETCFG 64 + 16
Or:
MSETCFG 80
Or in Hex:
MSETCFG &H50

There are separate AUTOEXEC files for Dragon and CoCo, this allows the same card to be used in both computers. Dragon has an AUTOEXEC file extension of .DGN and CoCo .CCO.

This example will create a simple welcome message every time the computer performs a cold boot, just turn the computer off and on again to see your new welcome message.

10 PRINT “WELCOME TO THE DMMC”
20 NEW
CWD “/”
MSAVE “AUTOEXEC.DGN”

To bypass the running of the AUTOEXEC, press the space bar during the cold boot.

SETTINGS

The DMMC saves the currently mounted virtual disks and location of the snapshot folder to the binary SETTINGS file into the root directory of the memory card. This allows disk images to remain mounted even after computer has been turned off.

There are separate SETTINGS files for Dragon and CoCo, this allows the same card to be used in both computers. Dragon has a SETTINGS file extension of .DGN and CoCo .CCO.

This file user editable and must be set with commands.

See Also:-
CWDS
MDISKI

Tape to CAS

The DMMC allows real cassette tape programs to be converted into a CAS file in a simple one step process. The MMIRROR command mirrors/copies tape data into a CAS format file as it’s loaded into the computer.

To create your own CAS file connect the tape deck and cassette lead as normal, then enter the MMIRROR command with the filename you wish to call the cassette image on the memory card:

MMIRROR "MYTAPE.CAS"

At the OK prompt type CLOAD or CLOADM to load the program and let the computer complete loading as normal. As the tape is being converted the red LED on the DMMC will blink occasionally.

Once the program has loaded correctly, press the snapshot button on the DMMC, this will finalise the mirror/copy process. You will need to press [X] key to exit the snapshot menu. The newly generated CAS file can now be loaded with the DMMC using the normal tape image commands or used in emulators.

### INDEX

^ Caret symbol in filenames | 11
↑ Up arrow symbol in filenames | 11
AUTOEXEC PROGRAM FILE | 59, 60
CAT Command | 9, 26
CATP Command | 27
CFTYPE Function | 13, 52
CFTYPEE Function | 52
CFTYPEL Function | 53
Clock | 7
COMMANDS | 26
Connecting Your DMMC Interface | 7
Create a directory | 36, 37
CWD Command | 10, 27, 28
DSK CoCo Disk Images | 9, 34
File extensions | 9
FINDFIRST$ Function | 21, 53
FINDNEXT$ Function | 21, 54
FLEX OPERATING SYSTEM | 16
FUNCTIONS | 52
Hardware Overview | 4
HELP/HELPX Command | 29
Loading Cartridge Images (ROM) | 13
Loading Cassette Images (CAS) | 12
Loding Disk Images (DSK/VDK) | 15
Long File Names | 11
Making Your Own Cassette Image (CAS) | 20
MCARTLOAD/MCARTLOADA Command | 13, 29
MCAS COMMAND | 12, 30
MDELETE Command | 31
MDISK OFF Command | 12, 16, 30, 32
MDISK ON Command | 15, 31
MDISKC Command | 16, 33
MDISKI Command | 15, 34
MDISKL Command | 15, 35
MDISKO Command | 16, 36
MGETCFG Function | 55
MGETDT$ Function | 7, 56

MGETINAME$ Function | 57
MKDIR Command | 36, 37
MLOAD/MLOADA Command | 22, 38
MLOADS Command | 19, 39
MMOUNTR Command | 12, 41
MMOUNTW COMMAND | 40, 42
MSAVE Command | 43
MSAVEM Command | 44, 59
MSETCFG Command | 7, 45, 46, 59
MSETDT Command | 7, 48
MTAPERUN Command | 12, 49
Pausing running programs | 18
Regenerate CAS files | 24, 61
RETOKC Command | 50
RETOKD Command | 50
REWIND Command | 13, 51
Setting the clock | 7
Setting Up A New Memory Card | 8
Snapshots | 14, 18
Troubleshooting loading CAS files | 23
Troubleshooting using disk images | 25
VDK Dragon Disk Images | 9, 34
VER Function | 57, 58
WD$ Function | 10, 58
What’s On My SD Card? | 8

THIS PAGE HAS INTENTIONALLY BEEN LEFT BLANK

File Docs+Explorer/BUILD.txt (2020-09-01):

This is the source archive for DragonMMC, it contains the following sections :

AVRFirmware.	

The firmware in C for the ATMega1284 microcontroller, to build this you will need the 
AVR command line tools available from the Atmel / Microchip website. 
Also included is the bootloader firmware for the microcontroller.

Dragon Firmware.

The 6809 code that makes up the new basic commands, DOS emulation and communication 
with the AVR microcontroller. This is built with lwasm, available from the lwtools 
website : http://www.lwtools.ca/

Xilinx firmware. 

The Verilog source and asociated support files needed to build the code for the 
XC95144XL CPLD on the board. This handles signal routing address decoding and latching
of data between the AVR microcontroller and the 6809.
To build this you will need Xilinx Webpack, at the time of writing this is available 
from : https://www.xilinx.com/products/design-tools/ise-design-suite/ise-webpack.html

Both the AVR and 6809 firmware is built from a Makefile, plus supporting utilities, if
you use a Linux / Unix based operating system these will generally already be installed.
If you use windows there are a number of options such as Cygwin / MINGW, under 
Windows 10 you may also be able to used "Windows Services for Linux". I personally use 
Cygwin.

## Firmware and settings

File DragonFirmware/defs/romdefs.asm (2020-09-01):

DStubResWordsOfs		EQU	$0000		Offset of number of reserved words
DStubResLookupOfs		EQU	$0001		Offset of reserved word lookup table
DStubResJumpOfs			EQU	$0003		Offset of reserved word jump table
DStubFuncsOfs			EQU	$0005		Offset of nummber of functions
DStubFuncsLookupOfs		EQU	$0006		Offset of function lookup table
DStubFuncsJumpOfs		EQU	$0008		Offset of functions jump table

DSkip1				EQU	$0021		Skip 1 byte (BRN)
DSkip2				EQU	$008C		Skip 2 bytes (CMPX)
DSkip1LD			EQU	$0086		Skip 1 byte (LDA)
DSkip2TST			EQU	$007D		Skip 2 bytes (TST)

DCoCoVec167			EQU	$0000		Vector dest for 167 
DCoCoVect16A			EQU	$0000		Vector dest for 16A
DCoCoVect176			EQU	$0000		Vector dest for 176
DCoCoVect179			EQU	$0000		Vector dest for 179
DCoCoVect18B			EQU	$0000		Vector dest for 18B
DCoCoVect191			EQU	$0000		Vector dest for 191
DCoCoVect194			EQU	$0000		Vector Dest for 194
DCoCoVect197			EQU	$0000		Vector Dest for 197
DCoCoVect19A			EQU	$0000		Vector Dest for 19A
DCoCoVect1A3			EQU	$0000		Vector Dest for 1A3
DAddrFWareRamTop		EQU	$0027		Top of firmware RAM CLEAR xxx,yyyy set this to yyyy
DAddrRamTop			EQU	$0074		Physical end of RAM (4K, 16K, 32K or 64K).
DAddrStack			EQU	$0021		Address of top of machine stack
DBasAddrCmdDisp			EQU	$0123		Address of basic command dispatch
DBasAddrCmdList			EQU	$0121		Address of basic command list
DBasAddrDskCmdDisp		EQU	$012D		Address of disk basic command dispatch
DBasAddrDskCmdList		EQU	$012B		Address of disk basic command list
DBasAddrDskFuncDisp		EQU	$0132		Address of disk basic function dispatcher
DBasAddrDskFuncList		EQU	$0130		Address of disk basic function list
DBasAddrFuncDisp		EQU	$0128		Address of basic function dispatcher
DBasAddrFuncList		EQU	$0126		Address of basic function list
DBasAddrSigByte			EQU	$00A6		Address of current significant bit in command line
DBasAOError			EQU	$B84E		Print ?AO Error and return to basic
DBasArrayEval			EQU	$0005		Array evaluation flag, 0=eval, 1=dimensioning
DBasBootBasic			EQU	$B400		Restart basic, as if power on, also deletes current program
DBasBotStack			EQU	$0017		Bottom of stack at last check
DBasBRARun			EQU	$84DA		BRA to main loop, used by DOS
DBasBreakFlag			EQU	$0000		Break flag, +ve=stop,-ve=end
DBasBuffer			EQU	$03D7		Basic buffer space
DBasChkArrSpaceMv		EQU	$831C		Check memory space at top of arrays + move arrays
DBasChkB2Free			EQU	$8331		Check B*2 bytes free above Arrays, OM error if not
DBasChkDirect			EQU	$9C76		Check for direct mode, ID Error if so
DBasChrGet			EQU	$009F		Get next basic character routine
DBasChrGetCurr			EQU	$00A5		Get current basic ccharacter
DBasCloadMOffs			EQU	$00D3		2s complement of CLOADM offset
DBasCmdMode			EQU	$8371		Return to command mode
DBasContLine			EQU	$0029		Line no used by CONT
DBasCurrentLine			EQU	$0068		Current line no $FFFF in direct mode
DBasDelim1			EQU	$0001		First string delimiter
DBasDelim2			EQU	$0002		Second string delimiter
DBasDirectTextPtr		EQU	$002F		Direct mode text pointer
DBasDisArraySearch		EQU	$0008		Disable array search flag, 0=allow 0<>disable
DBasDNError			EQU	$B851		Print ?DN Error and return to basic
DBasDoDispatch			EQU	$84ED		Do command dispatech, X must point to dispatch table
DBasEditorLineLen		EQU	$00D7		Editor line length
DBasErrorCodeTable		EQU	$82A9		List of 2 byte error codes eg 'SN' 'OM' 'UL' etc
DBasExecAddr			EQU	$009D		Exec address, on D64, at startup points to routine to boot all ram mode
DBasFCError			EQU	$8B8D		Print ?FC Error and return to basic
DBasFindLineNo			EQU	$83FF		Find a line number in basic program
DBasFMError			EQU	$B848		Print ?FM Error and return to basic
DBasGarbageFlag			EQU	$0007		Garbage collection flag
DBasGenCount			EQU	$0003		General count/scratch var
DBasGetDevNo			EQU	$B7D4		Get dev no from line & validate
DBasGetLineNo			EQU	$869A		Get line no and store in BasTempLine
DBasGetStrFirst			EQU	$8DEA		Get first character of string into B
DBasGetStrLenAddr		EQU	$8D9A		Get string len in B and address in X of string desc in FPA2
DBasicCassBitIn			EQU	$8027		Cassette bit input
DBasicCassByIn			EQU	$8024		Cassette byte input
DBasicCassByOut			EQU	$801E		Cassette byte output
DBasicCassOff			EQU	$8018		Cassette player motor off
DBasicCassOn			EQU	$8015		Cassette player motor on
DBasicCassOnRd			EQU	$8021		Cassette on for reading
DBasicCursorB			EQU	$8009		Cursor blink
DBasicHWInit			EQU	$8000		Hardware initialisation
DBasicJoyIn			EQU	$8012		Joystick input
DBasicKbdIn			EQU	$8006		Keyboard input
DBasicPrintOut			EQU	$800F		Printer output
DBasicScreenOut			EQU	$800C		Screen output
DBasicSerIn			EQU	$802A		Read a byte from serial
DBasicSerOut			EQU	$802D		Write a byte to serial port
DBasicSetBaud			EQU	$8030		Set baud rate
DBasicSWInit			EQU	$8003		Software initialisation
DBasicWriteLead			EQU	$801B		Cassette write leader
DBasIDError			EQU	$9C7C		Print ?ID Error and return to basic
DBasIfCount			EQU	$0004		If count - how many in a line
DBasInBuffFromX			EQU	$B5D3		Read input buffer at X as basic input
DBasInputFlag			EQU	$0009		Iinput/read flag, 0=input 0<>read
DBasIOError			EQU	$B84B		Print ?IO Error and return to basic
DBasIRQVec			EQU	$9D3D		Basic IRQ routine, increments timer
DBasJoyVal0			EQU	$015A		Joystick(0) value
DBasJoyVal1			EQU	$015B		Joystick(1) value
DBasJoyVal2			EQU	$015C		Joystick(2) value
DBasJoyVal3			EQU	$015D		Joystick(3) value
DBasLineInputEntry		EQU	$9DD9		Entry into LINE INPUT routine, used by DOS
DBasLinInpBuff			EQU	$02DC		Basic line input buffer
DBasLinInpHead			EQU	$02DA		Basic line input buffer header
DBasList			EQU	$8EAA		List basic program to SysDevN A must be 0 on entry
DBasListLine			EQU	$0066		Current line during list
DBasLocateScreen		EQU	$AA87		Initialise beginning of basic after graphics screen, no of pages in A
DBasLSError			EQU	$8D6B		Print ?LS Error and return to basic
DBasNEError			EQU	$A101		Print ?NE Error and return to basic
DBasNew				EQU	$8417		Remove current basic program from meory, like NEW command
DBasNOError			EQU	$B631		Print ?NO Error and return to basic
DBasNumCmds			EQU	$0120		Number of basic commands
DBasNumDskCmds			EQU	$012A		Number of disk basic commands
DBasNumDskFuncs			EQU	$012F		Number of disk basic functions
DBasNumFuncs			EQU	$0125		Number of basic functions
DBasOldInputPtr			EQU	$002D		Pointer to saved input during a STOP
DBasOMError			EQU	$8342		Print ?OM Error and return to basic
DBasOVError			EQU	$91DB		Print ?OV Error and return to basic
DBasPollKeyboard		EQU	$851B		Basic, poll keyboard and check for break
DBasRandom8			EQU	$978E		Generate an 8 bit random number and place in BasRandomSeed+1
DBasRandomSeed			EQU	$0115		Random number seed for RND function
DBasRelateFlag			EQU	$000A		Relational operator flag
DBasRenumStart			EQU	$00D1		Renum start line no
DBasRenumStartLine		EQU	$00D5		Renum start line number
DBasRenumVal			EQU	$00CF		Renum increment value
DBasResetStack			EQU	$8434		Reset basic stack to initial position
DBasResStr			EQU	$8C52		Reserve B bytes of string space return start in X, setup low mem vars
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

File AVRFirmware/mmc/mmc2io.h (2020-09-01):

#ifndef _IO

#include <avr/io.h>
#include <avr/pgmspace.h>
#include <avr/eeprom.h>

#define LOG_RESULT

#define REDLED		1
#define GREENLED	0

#define REDMASK		(1<<REDLED)
#define	GREENMASK	(1<<GREENLED)

#define LEDDDR		DDRB
#define LEDPORT		PORTB

#define LEDPINSOUT() 	LEDDDR |= (REDMASK | GREENMASK)

#define REDLEDON()		    LEDPORT &= ~REDMASK
#define REDLEDOFF()		    LEDPORT |= REDMASK
#define REDLEDTOGGLE()      LEDPORT ^= REDMASK
#define GREENLEDON()	    LEDPORT &= ~GREENMASK
#define GREENLEDOFF()	    LEDPORT |= GREENMASK
#define GREENLEDTOGGLE()	LEDPORT ^= GREENMASK

#define CARD_DETECT	2
#define WRITE_PROT	3

#define CARD_DETECT_MASK	(1<<CARD_DETECT)
#define WRITE_PROT_MASK		(1<<WRITE_PROT)

#define CARDIO_DDR	DDRB
#define CARDIO_PORT	PORTB
#define CARDIO_PIN	PINB

#define CARD_INSERTED()		(~CARDIO_PIN & CARD_DETECT_MASK)
#define CARD_WRITABLE()		(CARDIO_PIN & WRITE_PROT_MASK)

#define ASSERTIRQ()
#define RELEASEIRQ()

#define NOPDelay()		{ asm("nop; nop;"); }

/* Dataport for communication with host processor */
#define DATAPORT	PORTC
#define DATAPIN		PINC
#define	DATADDR		DDRC

#define SetIOWrite()	{ DATADDR=0xFF; };
#define SetIORead() 	{ DATADDR=0x00; };

/* OE line from input latch */
#define	OEPORT	PORTA
#define	OE		4		
#define OEMASK	(1 << OE)
#define OEDDR	DDRA

#define AssertOE()	{ OEPORT &= ~OEMASK; NOPDelay(); };
#define ClearOE()	{ OEPORT |= OEMASK; };

/* LE line for output latch */
#define	LEPORT		PORTA
#define	LE			5		
#define LEMASK		(1 << LE)
#define LEDDR		DDRA

#define AssertLE()	{ LEPORT &= ~LEMASK; NOPDelay(); };
#define ClearLE()	{ LEPORT |= LEMASK; };

/* Address pin, selects either latched address or data reg */
#define ADDRPORT	PORTA
#define ADDR		0
#define ADDRMASK	(1 << ADDR)
#define ADDRDDR		DDRA

#define SelectData()	ADDRPORT &= ~ADDRMASK
#define SelectAddr()	ADDRPORT |= ADDRMASK

/* Status lines so that AVR can signal status to Dragon */
#define ST_PORT		PORTA
#define ST_DDR		DDRA
#define ST_BUSY		6
#define ST_BUSYMASK	(1<<ST_BUSY)

#define SetBusy()	ST_PORT |= ST_BUSYMASK
#define ClearBusy()	ST_PORT &= ~ST_BUSYMASK

/* When reading status from Dragon */
#define RWLine			6
#define RWMask			(1 << RWLine)
#define ADDR_LINE_MASK	0x0F

#define MotorLine		7
#define MOTOR_MASK		(1 << MotorLine)

#define LatchAddressIn()				{ SelectAddr(); SetIORead(); AssertOE(); LatchedAddressLast=DATAPIN; ClearOE(); }
#define ReadDataPort()					{ SelectData(); SetIORead(); AssertOE(); LatchedData=DATAPIN; ClearOE(); }
#define ReadDataPortFast(outvar)		{ AssertOE(); outvar=DATAPIN; ClearOE(); }
#define WriteDataPort(value)			do { SelectData(); SetIOWrite(); DATAPORT=value; AssertLE(); ClearLE(); } while (0)
#define WriteDataPortFast(value)		do { DATAPORT=value; AssertLE(); ClearLE(); } while (0)

#define AddressPORT	
#ifdef LOG_RESULT
#define WriteStatus(status)					do { WriteDataPort(status); log0c(DEBUG_REPLY,"R:%02X\n",status); } while (0)
#else
#define WriteStatus(status)					do { WriteDataPort(status); } while (0)
#endif
#define WriteStatusCond(cond,tcond,fcond)	{ if (cond) WriteStatus(tcond); else WriteStatus(fcond); }

#define WASWRITE				((LatchedAddressLast & RWMask)==0) 
#define MotorIsOff				((LatchedAddressLast & MOTOR_MASK)==0)

#define ReadEEPROM(addr)		eeprom_read_byte ((const uint8_t *)(addr))	
#define WriteEEPROM(addr, val)	eeprom_write_byte ((uint8_t *)(addr), (uint8_t)(val))

#define _IO
#endif

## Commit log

2020-09-01 Initial commit of DragonMMC V1.30 firmware.
    [SizeBlocks.cfg]
2020-09-02 Added 3D files for printing case.
    [DragonMMCBottom-v3.FCStd, DragonMMCBottom-v3.stl, DragonMMCButtons-v3.FCStd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]
2021-02-04 Added drivers for OS-9 and procedure to merge them in. Added utilites disk for OS-9 to allow manipulation of disk images.
2021-02-11 OS9 integration, drivers and utilities for OS9 Bugfixes to firmware
